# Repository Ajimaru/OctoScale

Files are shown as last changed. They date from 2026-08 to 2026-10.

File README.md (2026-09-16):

<!-- markdownlint-disable MD033 -->
<p align="center">
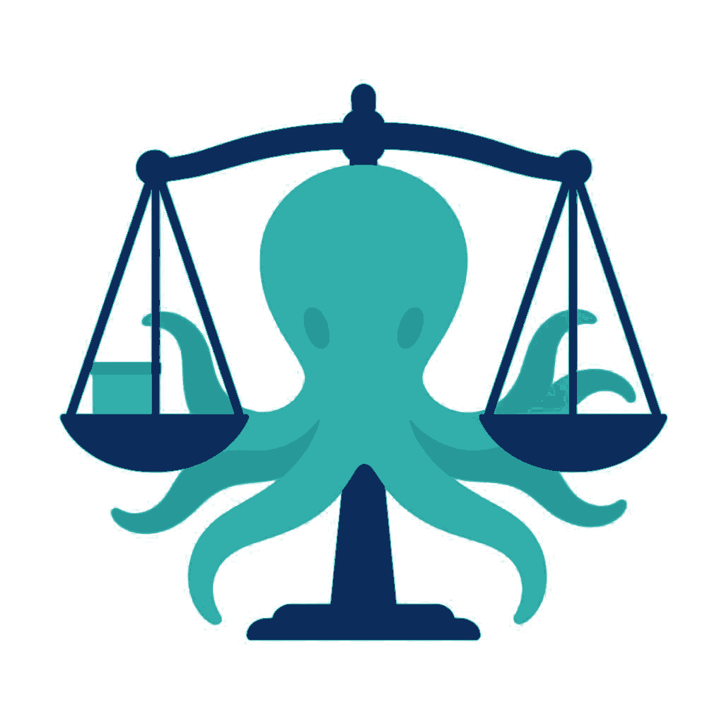
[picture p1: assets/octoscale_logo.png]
OctoScale
  
</p>

<p align="center">
  <b>NFC filament scale for OctoPrint + SpoolManagerExtended.</b><br>
  Weigh a spool, tap its tag, and load it into a printer or save its remaining weight.
</p>
<!-- markdownlint-enable MD033 -->

[](LICENSE)
[](https://github.com/Ajimaru/OctoScale/actions/workflows/build.yml)
[](https://www.espressif.com/en/products/socs/esp32-s3)
[](https://platformio.org)
[](https://github.com/Ajimaru/OctoScale/releases/latest)
[](https://github.com/Ajimaru/OctoScale/releases)
[](https://github.com/Ajimaru/OctoScale)

[badge-license]: https://img.shields.io/github/license/Ajimaru/OctoScale?style=flat-square
[badge-build]: https://img.shields.io/github/actions/workflow/status/Ajimaru/OctoScale/build.yml?style=flat-square
[badge-platform]: https://img.shields.io/badge/ESP32--S3-N16R8-blue.svg?style=flat-square
[badge-pio]: https://img.shields.io/badge/PlatformIO-Arduino-orange.svg?style=flat-square
[badge-release]: https://img.shields.io/github/v/release/Ajimaru/OctoScale?style=flat-square
[badge-downloads]: https://img.shields.io/github/downloads/Ajimaru/OctoScale/total.svg?style=flat-square
[badge-love]: https://img.shields.io/badge/made_with-%E2%9D%A4%EF%B8%8F-ff69b4?style=flat-square

> [!WARNING]
> Database features require [OctoPrint-SpoolManagerExtended](https://github.com/Ajimaru/OctoPrint-SpoolManagerExtended).
> Without it, the device still supports weighing, calibration, and NFC tag operations.

<!-- markdownlint-disable MD033 -->
<p align="center">
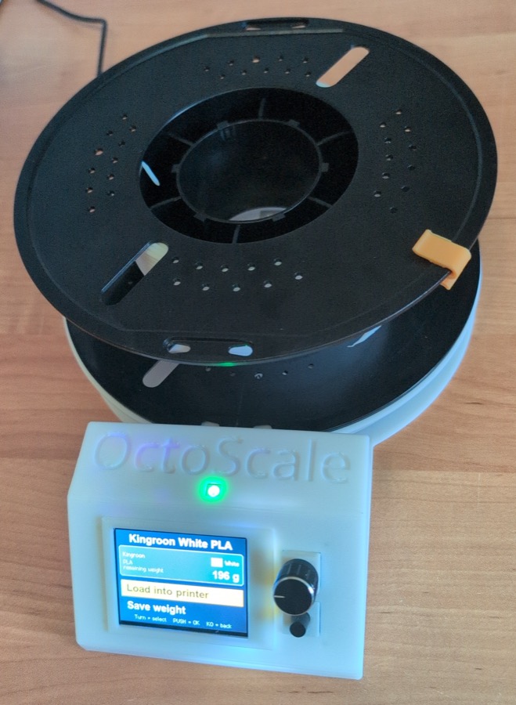
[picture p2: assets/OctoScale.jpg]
Assembled OctoScale with a spool on the scale
  
</p>
<!-- markdownlint-enable MD033 -->

## What it does

OctoScale combines an ESP32-S3, load cell, PN5180 NFC reader, TFT menu, and web UI into one filament-management appliance. It reads spool tags, looks them up in SpoolManagerExtended, loads them into an OctoPrint printer/tool, and writes measured weight back to the database.

It also supports standalone weighing and NFC tag read/write operations, OTA updates, multiple OctoPrint instances, database failover, encrypted configuration backups, and device diagnostics.

## Documentation

The complete build and maintenance documentation is in the Assembly Guide:

- [OctoScale Features](https://github.com/Ajimaru/OctoScale/wiki/Features) — supported scale, NFC, interface, connectivity, OTA, and backup features.
- [Hardware & Printing Guide](https://github.com/Ajimaru/OctoScale/wiki/Hardware-and-Printing-Guide) — hardware BOM and printable enclosure parts.
- [OctoScale Assembly Guide](https://github.com/Ajimaru/OctoScale/wiki/Assembly-Guide) — wiring, enclosure assembly, project layout, and core/task notes.
- [Setup Guide](https://github.com/Ajimaru/OctoScale/wiki/Setup-Guide) — firmware flash, prebuilt `octoscale-usb.bin` and `octoscale-ota.bin` downloads, OTA updates, and first-time setup.
- [Contributing](CONTRIBUTING.md)
- [Security policy](SECURITY.md)
- [Changelog](CHANGELOG.md)
- [License](LICENSE)

The full documentation is maintained in the [GitHub OctoScale Wiki](https://github.com/Ajimaru/OctoScale/wiki).

## License

GNU Lesser General Public License v2.1 or later — see [LICENSE](LICENSE).

Copyright © 2026 Ajimaru

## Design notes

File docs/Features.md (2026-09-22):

# OctoScale Features

NFC filament scale for OctoPrint and SpoolManagerExtended. This page summarizes the device capabilities and supported tag formats. See the [Assembly Guide](Assembly-Guide) for hardware, wiring, enclosure, firmware, setup, and maintenance.

## Scale

- HX711 and 5 kg load cell with live readout on the TFT and web UI.
- One-point quick calibration and two-point linearity-checked calibration.
- Calibration factor stored in NVS and retained across reboots and OTA updates.
- Zero point stored in NVS and checked against a fresh reading at every boot, so a restart while a spool sits on the scale cannot silently adopt that spool's weight as zero. An unconfirmed zero point is shown on the TFT and in the web UI and blocks saving a weight until the scale is tared. Requires a calibrated device.

## NFC

The PN5180 reads and writes NFC-A/NTAG/Ultralight, NFC-V/ISO 15693, and Mifare Classic 1K tags. Supported payload formats are auto-detected:

| Format | Tag | Notes |
| --- | --- | --- |
| `octoscaleExtended` | Mifare Classic 1K | Custom binary layout with CRC-8 commit marker |
| `ntagExtended` | NTAG | Same layout with NTAG page addressing |
| `nfcvExtended` | NFC-V | Same layout with NFC-V blocks |
| `openSpool` / `nfcvOpenSpool` | NTAG / NFC-V | OpenSpool NDEF/JSON, readable by third-party apps |
| `nfcvOpenPrintTag` | NFC-V | OpenPrintTag CBOR, including drying data |
| `tigerTag` | NTAG | TigerTag Standard, unsigned, big-endian 80-byte payload |

Foreign tags such as Snapmaker tags fall back to a UID lookup in SpoolManagerExtended. NFC writes report `droppedFields` when fields do not fit and `unsupportedFields` when the selected format has no representation. Unknown tags can be inspected with a raw sector/block dump.

## Interface and connectivity

- ST7789 320x240 TFT with EC11 encoder menu mirroring the spool workflow.
- Boot splash, locked OTA progress screen, and independent light/dark display theme.
- Three idle stages: dim, bouncing-logo screensaver, and display/backlight off.
- Hidden device test menu: hold PUSH for 3 seconds on the System info screen.
- Web UI themes: OctoScale and OctoPrint, each with light/dark mode.
- Web UI covers weighing, calibration, NFC, OctoPrint instances, system, WiFi, and test points.
- Passive buzzer with event tones and mirrored onboard/external WS2812 status LEDs.
- Optional browser debug console for NFC and HTTP activity.
- WiFiManager provisioning with AP fallback and captive portal.
- OTA through `espota` or web upload/URL update.
- Multiple OctoPrint instances with database failover when instances share an external database.
- AES-256-CBC encrypted JSON backup of the full configuration, including all display, buzzer, and LED settings; API keys are never exported in plaintext.

Continue with the [Hardware & Printing Guide](Hardware-and-Printing-Guide) to gather components and print the enclosure parts.

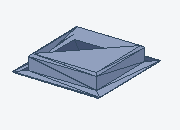
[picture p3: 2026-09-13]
assets/stl-previews/OctoScaleLEDCover.png

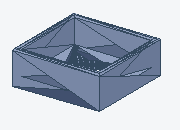
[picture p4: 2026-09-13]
assets/stl-previews/OctoScaleKnobCover.png

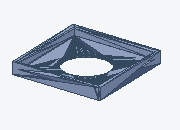
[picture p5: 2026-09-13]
assets/stl-previews/OctoScaleButtonCover.png

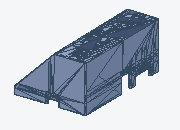
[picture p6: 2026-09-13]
assets/stl-previews/OctoScaleLit.png

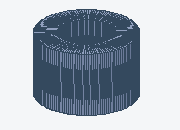
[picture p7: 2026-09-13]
assets/stl-previews/OctoScaleSpacer.png

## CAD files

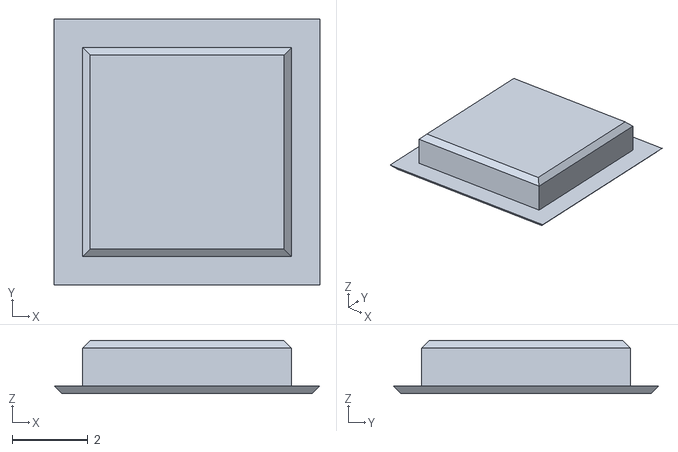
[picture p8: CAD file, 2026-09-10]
stl_files/OctoScaleLEDCover.stl
7.00 x 7.00 x 1.40

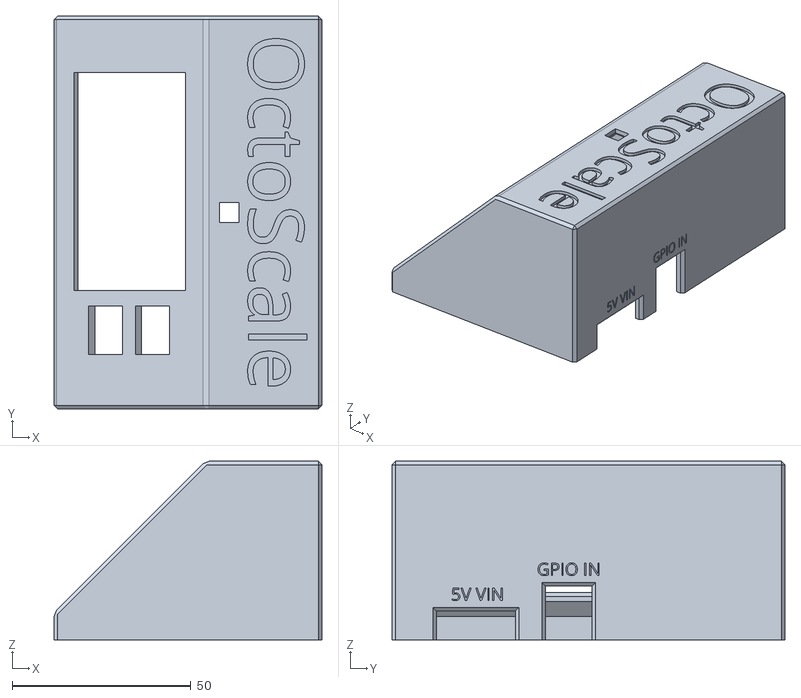
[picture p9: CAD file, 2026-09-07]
stl_files/OctoScaleLit.stl
75.0 x 110.0 x 50.0

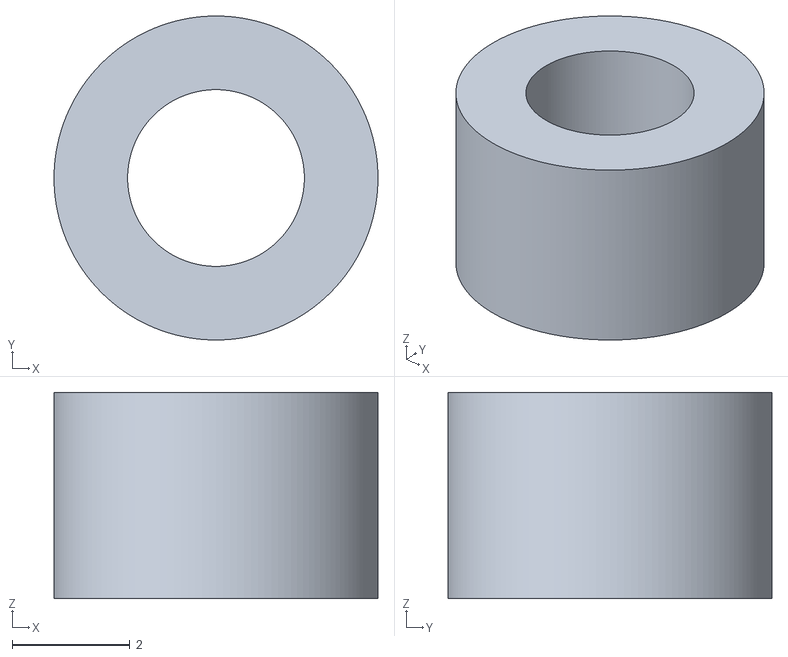
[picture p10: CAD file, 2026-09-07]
stl_files/OctoScaleSpacer.stl
5.50 x 5.50 x 3.50

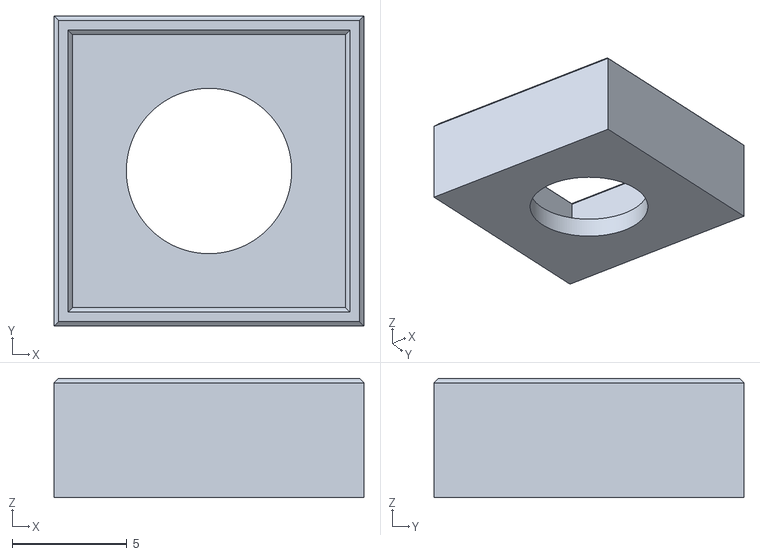
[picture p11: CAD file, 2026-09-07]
stl_files/OctoScaleKnobCover.stl
13.5 x 13.5 x 5.20

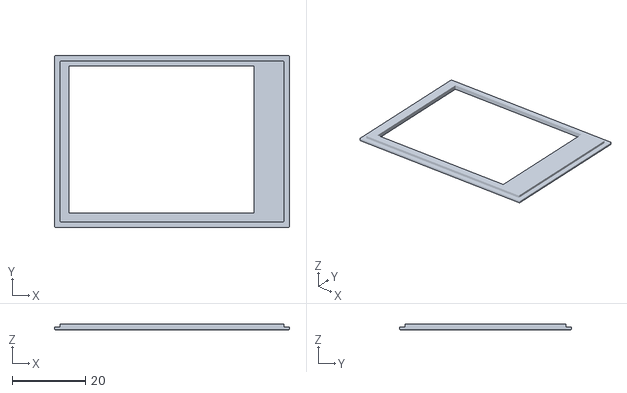
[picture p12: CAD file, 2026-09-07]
stl_files/OctoScaleScreenBazel.stl
64.1 x 47.0 x 1.60

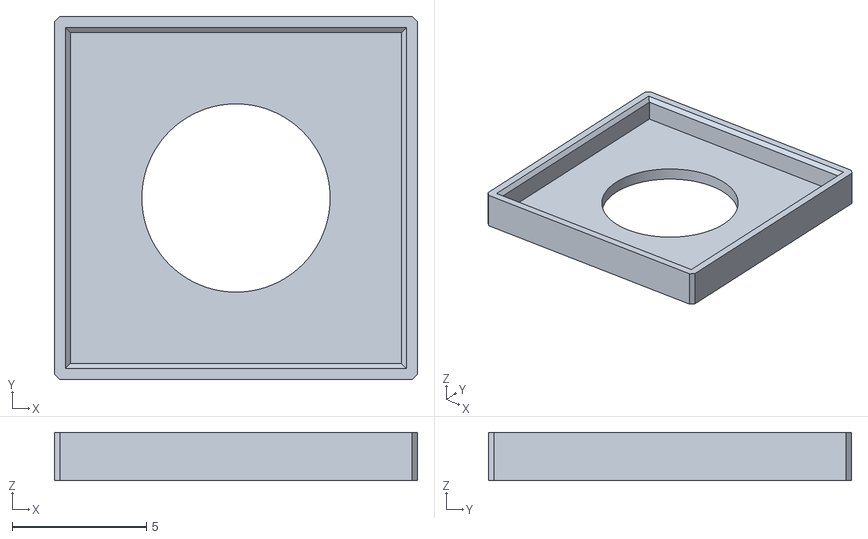
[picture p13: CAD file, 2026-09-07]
stl_files/OctoScaleButtonCover.stl
13.5 x 13.5 x 1.80

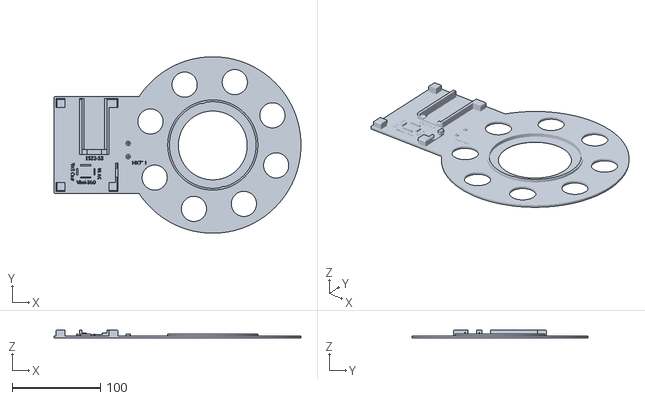
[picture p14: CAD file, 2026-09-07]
stl_files/OctoScaleBottom.stl
280.0 x 200.0 x 9.50

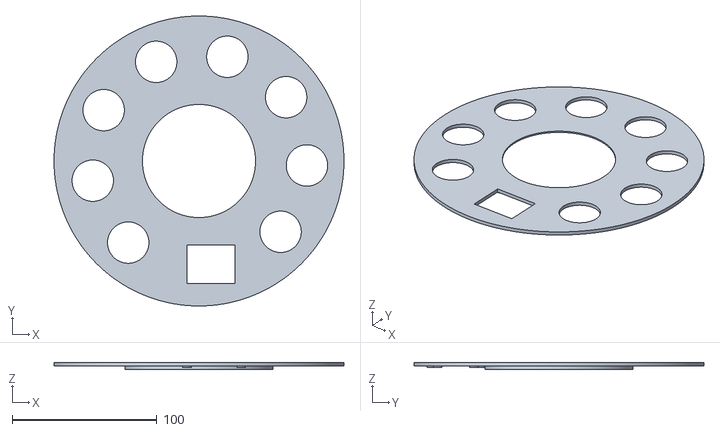
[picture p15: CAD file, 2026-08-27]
stl_files/OctoScale_Top.stl
200.0 x 200.0 x 5.00

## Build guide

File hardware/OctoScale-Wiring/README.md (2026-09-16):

# OctoScale wiring schematic

KiCad 10 project for the wiring diagram in the [Assembly Guide](../../docs/Assembly-Guide.md).
It documents how the modules are wired together; there is no PCB, because the
build is point-to-point wiring between ready-made boards.

## Files

| File | Purpose |
| --- | --- |
| `OctoScale-Wiring.kicad_pro` | project file — open this in KiCad |
| `OctoScale-Wiring.kicad_sch` | the schematic |
| `OctoScale-Modules.kicad_sym` | module symbols (see below) |

## Why a local symbol library

KiCad's stock libraries carry the bare *chips*: `Analog_ADC:HX711` has sixteen
pins named `BASE`, `VFB`, `XI`, `XO` and `RATE`. The board in the BOM is a
breakout with eight labelled holes — `E+ E- A- A+` and `VCC GND DT SCK`. Someone
holding that board cannot match it against the chip symbol without a datasheet.

So every module here is drawn with the pin names printed on its own silkscreen.
Stock symbols are used where they already match what the builder sees:
`Device:Buzzer`, `Device:C_Polarized` and the `power` symbols.

## Checks

The schematic passes ERC with no errors and no warnings:

```bash
kicad-cli sch erc --severity-all --output erc.rpt OctoScale-Wiring.kicad_sch
```

ERC only proves the drawing is self-consistent. That the nets match the firmware
is a separate question, so the netlist is checked against the pin constants in
`src/main.cpp`:

```bash
kicad-cli sch export netlist --output net.net OctoScale-Wiring.kicad_sch
```

All nineteen signal nets, plus the `+5V`, `+3V3` and `GND` rails, were verified
against `src/main.cpp` this way. When a pin assignment changes in the firmware,
update `generate_schematic.py` and re-run that comparison.

## Exports

Images used by the wiki live in `assets/wiring/`:

```bash
kicad-cli sch export pdf --output ../../assets/wiring/OctoScale-Wiring.pdf OctoScale-Wiring.kicad_sch
kicad-cli sch export svg --no-background-color --output ../../assets/wiring OctoScale-Wiring.kicad_sch
```

The PNG in that folder is rendered from the PDF; the wiki embeds the PNG because
GitHub does not render SVG reliably inside `<img>`.

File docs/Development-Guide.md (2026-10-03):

# OctoScale Development Guide

This guide collects public development notes for the ESP32-S3-N16R8 target.

## Target hardware

The supported reference board is an ESP32-S3-N16R8 development board:

- ESP32-S3, dual-core Xtensa LX7
- 16 MB flash
- 8 MB octal PSRAM (OPI)
- WiFi and BLE
- PlatformIO board: `esp32-s3-devkitc-1`
- Environments: `esp32s3` for USB and `esp32s3_ota` for OTA

The firmware does not use PSRAM directly, but the N16R8 memory configuration is required for the reference board to boot correctly. Other ESP32-S3 boards need matching flash and memory settings in `platformio.ini`.

## Build and flash

The first flash is performed over USB with the external power supply disconnected:

```bash
pio run -e esp32s3 -t upload
```

Regular updates use OTA:

```bash
pio run -e esp32s3_ota -t upload --upload-port <device-ip>
```

Use an IP address for OTA. Hostname resolution through mDNS can introduce long delays on some development hosts. Close the serial monitor before flashing; an open monitor can keep the serial port busy and prevent the bootloader handshake.

The reference board uses a WCH USB-UART bridge. The firmware is configured to use UART0 for the serial console rather than native USB-CDC. Keep the USB-CDC boot setting consistent with `platformio.ini` when changing board configurations.

### Dev build numbering

Every local build appends a running number to the version it reports — `0.0.3-dev7` rather than `0.0.3` — and copies its images into `artifacts/`. Flashing the same release version twice is otherwise indistinguishable on the display, in the web UI and over HTTP, which makes "which build is on the device?" unanswerable during a test session.

`tools/dev_build.py` runs as a pre-script for both environments. It increments a counter, passes the result in as `FW_DEV_BUILD`, and after linking writes `artifacts/octoscale-<version>-<env>.bin`, the identical `-ota.bin`, and the matching `.elf`. Keep the `.elf`: a backtrace from the serial monitor cannot be resolved once the build it came from has been overwritten.

The counter lives in `artifacts/.devcounter`, outside version control by way of `artifacts/` already being ignored. A number that changes on every build would otherwise make every test flash look like a source change. `src/version.h` keeps the release number in `FW_VERSION_RELEASE` and falls back to it when `FW_DEV_BUILD` is absent, so a clean checkout reports a plain version with no dev suffix. Rename one of those macros and the script's pattern has to follow, or the version silently reads as `0.0.0`.

`tools/dev_build.py` runs as a pre-script for *every* build via the shared `s3_base` environment, including CI — a release build is not naturally exempt. The release workflow (`.github/workflows/release.yml`) sets `OCTOSCALE_RELEASE_BUILD=1` before invoking `pio run`; the script checks that flag and, when set, skips both the dev suffix and the `artifacts/` archiving, so the published firmware reports the plain `FW_VERSION_RELEASE` instead of `<version>-dev<N>`.

Check what actually shipped by reading the binary rather than the build log, which only shows what the script intended:

```bash
strings artifacts/octoscale-0.0.3-dev1-esp32s3.bin | grep -o "0\.0\.3-dev[0-9]*"
```

The dev number separates local builds from each other; it does not make released versions unambiguous. Twenty-one commits shipped between the 0.0.2 and 0.0.3 bumps, all reporting the same version. Treat `fwVersion` and `currentVersion` as diagnostics rather than as a behaviour switch, and do not branch on them: a version that stays constant across that many commits separates nothing, and a later bump marks only devices built after it, never the ones already in the field. Where a consumer needs to know whether a capability exists, test for the field itself — `idSource` is simply absent on firmware that predates it.

## Boot and memory configuration

The ESP32-S3-N16R8 configuration requires:

- `board_build.arduino.memory_type = qio_opi`
- `-DBOARD_HAS_PSRAM`
- USB-CDC-on-boot disabled for the UART0 console configuration

Without the OPI memory setting, an N16R8 board may compile successfully but fail during boot. For boards without octal PSRAM, remove the PSRAM build flag and use the board's correct memory type. Boards with less than 8 MB flash need a custom partition layout and are not supported by the default OTA setup.

## Core split and ownership

The firmware deliberately separates blocking hardware work from networking:

- Core 0 runs `scaleTask` for the HX711 and `pn5180Task` for NFC polling, TFT menu work, and encoder input.
- Core 1 runs `loop()` with WiFi, HTTP, OTA, database checks, and flow delegation.
- Blocking NFC operations stay on core 0 because the PN5180 library contains unbounded wait loops.
- Flow actions that require blocking HTTP calls are passed to `loop()` through volatile state/flags.

A new hardware operation must not block the web server. Keep ownership of each peripheral within its task and communicate across cores with the existing state and flag pattern.

`pn5180Task` iterates at roughly 100 Hz for encoder debounce and menu work. Only the tag poll is throttled, by `PN5180_POLL_INTERVAL_MS` in `src/main.cpp`. Write, erase, and read requests are picked up on every iteration, so they are unaffected by that interval. Express any duration in this task in real milliseconds rather than as a count of poll ticks: a tick count silently changes meaning whenever the interval moves, which is how error screens once stayed up for a different length of time than intended.

## Pin map

The reference pin assignment is collision-checked against ESP32-S3 strapping pins, USB pins, and OPI flash/PSRAM pins.

| Peripheral | Signal | GPIO / supply |
| --- | --- | --- |
| HX711 | `DOUT`, `SCK` | 5, 6; 3.3 V |
| PN5180 FSPI | `MOSI`, `SCK`, `MISO` | 11, 12, 13 |
| PN5180 | `NSS`, `BUSY`, `RST`, `IRQ` | 10, 14, 21, 47 |
| TFT HSPI | `SCL`, `SDA` | 42, 44 |
| TFT | `CS`, `DC`, `RES`, `BLK` | 38, 39, 40, 41 |
| Encoder | `A`, `B`, `PUSH` | 15, 16, 17 |
| Start button | `KO` | 18 |
| Passive buzzer | signal | 7 |
| Onboard WS2812 | data | 48 |
| External WS2812 | data | 9 |

Do not reuse GPIO 0, 3, 45, or 46 (strapping), GPIO 19 or 20 (USB), or GPIO 26-37 (OPI flash/PSRAM on the reference board). GPIO 44 is often labelled `RX` on the development board. GPIO 43 is the UART0 transmit pin and should remain reserved when serial monitoring is needed.

## SPI buses

The PN5180 and TFT must use separate SPI controllers:

- PN5180: FSPI, GPIO 11/12/13
- TFT: HSPI, GPIO 42/44

Sharing the buses can leave the PN5180 unable to read tags after TFT initialization. The TFT is write-only and therefore does not need MISO. Keep `USE_HSPI_PORT` enabled for the TFT_eSPI configuration.

## Power requirements

The external 5 V supply powers the PN5180 RF section and TFT. A regulated 3.3 V rail powers the HX711, PN5180 logic, and external WS2812. All modules must share ground.

The PN5180 needs a 470 uF capacitor directly across its 5 V and ground pins. RF current spikes can otherwise collapse the supply and appear as a software or SPI failure. Do not power the ESP32-S3 from USB while an external 5 V supply is connected to its 5 V/VBUS/VIN input.

Two more electrolytic capacitors buffer the rest of the build:

| Position | Part | Buffers |
| --- | --- | --- |
| ESP32-S3 `5V` to `GND` | 1500 uF, 10 V+ | the board's own supply through WiFi transmit bursts |
| Mini-360 `OUT+` to `GND` | 100 uF, 16 V+ | the 3.3 V rail feeding HX711 and PN5180 logic |

Mount both with short leads directly at the pins they buffer; a few centimetres of wire undoes most of the benefit. Observe polarity.

The 3.3 V capacitor belongs at the **converter output**, not at the ESP32-S3's `3V3` pin. That pin is an output of the board's own regulator and feeds nothing in this build — HX711 and PN5180 logic hang on the Mini-360. A large capacitance on a regulator's output also does it no favours.

If the device resets unpredictably, read `resetReason` from `/system` first: value 9 is a brownout and points at the supply path rather than at firmware. Prefer a short, thick, direct connection, and put any remote power switching on the mains side of the 5 V supply rather than in the low-voltage path.

## Input handling

The EC11 encoder uses quadrature interrupts on both rotation pins. PUSH and KO use interrupt-latched button events with debounce. This prevents a button press from being lost while the reader is inside a blocking NFC operation. Preserve this event-latching behavior when adding controls.

The encoder and buttons use internal pull-ups; the other side of each switch connects to ground. If rotation direction is reversed, swap the A and B signals.

## NFC development

`src/pn5180nfc.h` supports NFC-A/NTAG/Ultralight, NFC-V/ISO 15693, and Mifare Classic 1K. The PN5180 library is vendored under `lib/PN5180 Library/` and contains project patches; consult `lib/README-patch.md` before changing it.

The reader supports database-ID writes as well as extended spool payloads. Extended payload formats are selected by tag family and can include material, vendor, color, diameter, weights, and temperatures. NFC-V and NTAG formats may use either the project layout or OpenSpool-compatible NDEF where supported.

Keep NFC work asynchronous at the HTTP boundary: start operations with the existing start endpoints, poll their status endpoints, and avoid long reader calls in request handlers. The three single-shot status endpoints — `/nfcwritestatus`, `/nfcdumpstatus` and `/nfcreadstatus` — each hand out their result exactly once and clear it, so a second reader cannot tell "someone already collected it" from "nothing happened". Pass `?peek=1` to read without consuming (and, on the write status, without the LED flash that announces the outcome) when something other than the issuing client wants to follow along. Keep the three consistent: `peek` was first added to the write status alone, and the gap on the dump endpoint was found by an external consumer rather than here. A fourth status of this shape needs the same flag. Unknown tags can be inspected through the raw dump/image paths without changing the normal spool flow.

### Vendored PN5180 patches

The local PN5180 library contains four project changes documented in `lib/README-patch.md`:

1. BUSY-pin waits have a timeout instead of an unbounded loop. A non-conforming tag must produce a clean failure rather than hanging the reader task indefinitely.
2. `mifareAuthenticate()` implements the PN5180 `MIFARE_AUTHENTICATE` host command, which is required for Mifare Classic sector access.
3. The IRQ wait loops in `setRF_on()`, `setRF_off()`, and `reset()` have timeouts. Upstream spins on these without any bound, so an unresponsive chip starves the reader task on core 0 and trips the task watchdog — a reboot with no log at all when the device runs from external power with no serial host attached.
4. ISO 15693 command handling waits for the reception interrupt instead of a fixed `delay(10)`. The old fixed delay discarded answers from slower tags as "no card". The wait is split in two: first for the start of a frame, bounded tightly because that timeout is paid on every empty poll, then for reception to complete. Do not collapse these back into a single check — a write is only acknowledged after the tag's internal programming cycle, so the frame legitimately has not started yet when the command returns.

Recheck all four when updating the vendored library. NFC-A probing also requires CRC to be disabled for REQA/ATQA and anticollision frames. Seven-byte UIDs need the cascade-level anticollision sequence. Mifare Classic writes use a two-step command/data exchange, while NTAG page writes require a fresh RF reset and re-selection for each page. After NFC-A work, restore the reader with `reset()` and `setupRF()` before returning to normal NFC-V polling.

The legacy database ID is an ASCII decimal value stored in the tag's legacy area. Extended payload reads happen before flow lookup and take priority over the legacy ID. This ordering matters because an OpenSpool NTAG payload can overwrite the legacy pages and stores its ID as `os_db_id` in the NDEF/JSON data instead.

### Trusting a parsed database ID

The legacy layout is digits followed by space padding, with no magic number and no checksum. Nothing in it identifies the tag as ours. A third-party tag that happens to carry ASCII digits at the same offset — an inventory number, for instance — parses exactly like a tag this firmware wrote, and no amount of reading that field harder can tell the two apart.

The parser therefore only rejects shapes our own writers cannot produce: trailing content that is not padding, more than one run of digits, a leading zero, or more than ten digits. Everything surviving that is plausible, not proven.

It also requires the digit run to end inside the buffer it was given, with at least one padding byte visible. `pn5180ReadNfcvId` passes however many bytes it managed to read, so a block failing mid-field used to yield a prefix of the real ID — a five-digit ID read as four bytes returned a different, entirely plausible, wrong spool, with no error anywhere. The ten-digit ceiling is mirrored in the three ID writers; a wider value would be written and verified, then read back as `-1` for the rest of the tag's life.

Proof, where it exists, comes from a second source. `occupancy` reads the Capability Container and the start of the data area, so it knows whether the tag carries a format this firmware wrote; the ID parser reads a fixed offset and knows nothing about the CC. `/nfcprobe` reports the combined judgement as `idSource`:

| `idSource` | Meaning |
| --- | --- |
| `extended` | The ID arrived with a verified format magic (`OX`, `OS`, OpenSpool NDEF, TigerTag). As trustworthy as the format it came from. |
| `legacy` | The ID came from the header-less field and passed the shape check. Plausible, unverifiable. |
| `unverified` | A `legacy` ID on a tag whose `occupancy` is `foreign`. The data area belongs to a format this firmware did not write, so the digits are most likely someone else's numbering. |
| `extendedNoId` | A verified format that carries no database ID of ours at all — TigerTag and OpenPrintTag both describe a spool without referencing this database. |
| `""` | No ID was parsed. |

`extendedNoId` is deliberately not `""`. Both mean "no usable ID", but the tag is not blank: it holds structured data from a format this firmware can read. A consumer that collapses the two will offer to overwrite a TigerTag.

A tag that has just been placed on the reader is published in two steps: type and UID appear as soon as it answers, because the display needs them at once, while the ID and the format fields are only filled after the Extended read and the occupancy probes have run — a few hundred milliseconds on NTAG. `/nfcprobe` reports `complete: false` for that window. A consumer that polls continuously can ignore the flag and watch the fields settle; one that asks once and acts on the answer should require `present && complete`, or it may see an Extended tag as an empty one and offer to overwrite it. Firmware older than this field omits it, so treat a missing value as unknown rather than as false.

`idSource` is a reported judgement, not an input to the flow. The load flow reaches its own verdict from the raw values — `hasExtendedData` and `occupancy` — and `flowWouldUse` only consults `idSource` to exclude `unverified`. Keep it that way: the firmware decides on what it read, the consumer receives the summary. It also means the current formats' habit of leaving `idParsed` at `-1` whenever `extendedNoId` applies is a property of those formats, not a guarantee of the field. A future format with both a verified magic and a populated legacy area would break that assumption, so do not build logic on it without checking the callers again.

`idParsed` keeps the raw value even when `idSource` is `unverified`, because `/nfcprobe` is a diagnostic endpoint and "there are digits here, but they are not credible" is worth more to a caller than a bare `-1` that cannot be told apart from an empty field. The judgement, not the value, is what consumers should branch on. `flowWouldUse` and the load flow both refuse an `unverified` ID and fall back to the UID lookup.

Note that `occupancy` alone is not that judgement. A tag written through `/nfcwriteid` onto previously NDEF-formatted material reports `foreign` while carrying a perfectly real ID, and an extended tag can report `foreign` because `occupancy` only inspects the CC and the first user page. Branching on `occupancy` instead of `idSource` discards both. Firmware older than this field omits it entirely, so a consumer that needs to support both should treat a missing `idSource` as "unknown, ask the user" rather than inferring one from `occupancy`.

`writeFormat` and `formatLabel` answer a different question again: which format this firmware *would* write if asked right now. They are derived from the tag family alone and say nothing about what is currently on the tag — every non-Classic NFC-A tag reports `openSpool` whether or not it holds any NDEF at all. Use `hasExtendedData`, `occupancy`, and `idSource` to find out what a tag actually carries.

## Display, LED, and buzzer

The TFT uses TFT_eSPI configured through `platformio.ini` build flags. The backlight is controlled by LEDC PWM on GPIO 41; do not hand the backlight pin to TFT_eSPI in a way that lets display initialization override the PWM. At runtime only `pn5180Task` writes the backlight: `/backlight` and `/display` set the level and count as activity, and the task applies it on its next loop pass. Level 0 detaches LEDC and holds the pin LOW as a plain GPIO. Coming back, the pin is re-attached before the level is written: `ledcAttachPin()` re-applies the duty it reads back, and the read-back shows a new duty only from the next PWM cycle on.

The display is off in the third idle stage and whenever the target brightness is 0. Off means backlight off on an all-black frame with the controller awake; `DISPOFF`+`SLPIN` would save about 15 mA, but on the reference panel backlight flashes were visibly stronger in sleep mode (cause not established). Nothing is drawn while off, and the input that wakes the display is consumed.

The onboard WS2812 on GPIO 48 and the external enclosure LED on GPIO 9 are mirrors. Drive both through the shared LED helper so color and timing stay synchronized. The passive buzzer uses LEDC PWM and shares event state with the LED pulse logic.

The LED base states are boot/WiFi connection, AP provisioning, connected/idle, database check, NFC result, and OTA progress. OTA has priority over normal animation; buzzer-linked colors have priority over the idle breathing effect. Keep all normal pixel writes behind the shared LED helper so the two pixels cannot drift apart or compete for the RMT peripheral. The idle breathing effect is deliberately low brightness. If colors are wrong, check whether the module is wired RGB rather than GRB before changing firmware behavior.

The TFT has four important takeover screens: the boot splash, the idle logo screensaver, the OTA lock screen, and the NFC-write screen. OTA suppresses backlight dimming and consumes input until the update finishes. NFC writes are blocking inside the reader task, so the write screen is intentionally static; a timer animation would not advance while the task is inside the write call. A completed write screen remains until the HTTP status result is consumed.

## Debug console and memory

The optional web debug console is an in-RAM ring buffer intended to replace serial monitoring when the device runs from external power. Logging is inert while disabled. Keep the buffer bounded and avoid serializing it when free heap is low: `/debuglog` should fail clearly rather than allocating a second large contiguous JSON string and taking down the web server. High-frequency traces, such as repeated successful Mifare authentication or unchanged weight readings, must be gated or rate-limited. Prefer chunked streaming if substantially more history is ever needed.

Display wakes are logged once per quiet period as `Display: activity (<source>) after <n>s idle`, which names an unexpected waker directly. The console's *Backlight trace* switch (`/debuglog?bldiag=1`, reported as `blDiag`, not persisted) adds a `BL diag` line every 10 s: idle time, target, current and read-back level (`hw`), and whether the display is off.

`/diag` switches off suspected sources of display interference one at a time, without a reflash. Nothing it sets is persisted; without parameters it returns the current state as JSON. The response also carries `asleep` (display off), `blPwm` (LEDC attached to the pin) and `blHw` (duty read back from the LEDC channel, 256 = fully on).

| Parameter | Effect |
| --- | --- |
| `nfc=0` / `nfc=1` | Pause the tag poll with the PN5180 RF field off / resume. No tags are detected while paused. |
| `led=0` / `led=1` | Stop LED updates with both pixels dark / resume |
| `tx=34`…`84` | WiFi TX power in 0.25 dBm steps (80 = 20 dBm, the default) |
| `panelsleep=1` / `0` | Display off uses `DISPOFF`+`SLPIN` / the awake black frame; applies at the next off |

## WebUI polling and tab ownership

The WebUI is embedded in `src/web_ui.h`. Periodic status requests are owned by the tab that displays their data. The `currentTab` guard prevents hidden panels from polling, and the browser visibility guard stops all periodic requests while the page is hidden. Selecting a tab triggers one immediate refresh; the regular timer then continues only while that tab remains active.

| Tab | Endpoint | Interval |
| --- | --- | ---: |
| Operate | `/weight` | 500 ms |
| Operate | `/flow/status` | 800 ms |
| NFC | `/nfc5180` and `/flow/status` | 700 ms |
| Scale | `/scaleinfo` | 1000 ms |
| Setup | `/wifi/status` | 5000 ms |
| System | `/system` | 3000 ms |
| Debug | `/nfcdebug` | 700 ms |
| Debug diagnostics | `/nfc5180`, `/scaleinfo`, `/weight` | 1000 ms |

`/weight` answers `<grams>|<zeroState>|<deviation g>` as plain text rather than a bare number. The zero-point verdict rides along on that poll instead of being fetched separately so the Operate tab's reading and its warning can never disagree on screen; a consumer that only wants the weight takes the first field.

The Debug tab has two additional conditional loops. The menu preview polls `/menupreview` every 300 ms only while the preview is active. The debug console polls `/debuglog` every 500 ms only while debug logging is enabled. These loops stop when the Debug tab is left or the browser page is hidden.

The header status LEDs are the one deliberate exception to tab ownership: they poll `/system` and `/wifi/status` every 10 s regardless of the active tab, because they are visible from all of them. They are still gated on page visibility, and the visibility handler refreshes them on return so they do not show stale state.

Any self-rescheduling loop needs both guards, not just the visibility one. The preview auto-cycle in particular kept stepping the device's screens from a switched-away tab, and an active preview suppresses NFC polling on the device — so a forgotten auto-cycle silently stopped tag detection while the page looked idle. When adding a loop that reschedules itself with `setTimeout`, check `document.hidden` and `currentTab` on every iteration, and make sure the tab's `tabRefresh()` path restarts it.

The intervals are intentionally different: live weight and flow state need responsive updates on Operate, while WiFi and system metrics can use a lower rate. Avoid adding a global timer for a panel-specific endpoint. Add the endpoint to the owning tab's `tabRefresh()` path and wrap its periodic callback with `pv(callback, tabId)` so it cannot continue polling in the background.

The page also performs one-shot requests during startup and user actions, such as loading `/factor`, `/display`, `/led`, `/buzzer`, `/db/get`, and OctoPrint configuration. These are not periodic status polls and should remain tied to the relevant initialization or action unless a new live status requirement is introduced.

## Spool flow architecture

The UI-independent flow is:

`idle -> db_check -> ask_action -> ask_printer -> ask_tool -> loading` or `weigh_confirm -> weighing -> done/error`

The reader task detects the tag and raises a flow request. The networking loop performs the blocking SpoolManager call. Database lookup uses the database ID when one is available and credible, and falls back to the tag UID for foreign tags. An ID parsed out of the header-less legacy area of a tag whose `occupancy` is `foreign` is deliberately not used (see "Trusting a parsed database ID"); the flow treats such a tag as having no ID at all and says so on the display, rather than silently loading whichever spool happens to share that number. Loading fetches the printer's tool count before selecting a tool. Weighing uses the live gross reading and only offers a remaining-weight calculation when empty and total spool weights are known.

Tag removal keeps action/printer/tool selection open for the configured timeout. The weighing states are exempt because the spool can hide its tag while it remains on the scale. Keep this state-machine behavior independent of whether the request came from the TFT or web UI.

## Persistent configuration and backup

Preferences are stored under the `octoscale` namespace. Important keys include the calibration factor, the tare offset and the factor it was written under, OctoPrint instance JSON, selected database instance, selection timeout, display brightness/timeouts, screensaver settings, buzzer settings, and debug-console enablement. WiFiManager stores WiFi credentials separately.

Configuration backup is JSON. API keys are encrypted only when a passphrase is supplied, using PBKDF2-HMAC-SHA256 and AES-256-CBC with a random salt and IV. Without a passphrase, keys are omitted rather than exported in plaintext. Restore validates and decrypts the complete file before writing anything to NVS, so a bad password must leave the running configuration unchanged. The backup protects the file, not an unencrypted LAN transport.

Device settings travel in a `settings` object addressed by NVS key, driven by the `BK_SETTINGS` table in `backup.h`. Adding a setting means adding one row there; export and import both walk the same table, so they cannot drift apart. Each row records the width the value is written with, because Preferences returns 0 when a `uint8` key is read back as `uint16`. Export skips keys that were never written, and import skips keys the file does not contain — an old backup therefore leaves newer settings at the running firmware's defaults instead of resetting them, which is also why the format version stays at 1. The table goes through NVS rather than the matching globals because `g_menuDark` is file-static in `menu.h`, included long after `backup.h`.

`bkImport` only writes NVS. The `/restore` handler re-reads those keys into the globals afterwards and re-applies the theme and LED routing, since the running firmware holds them in RAM; without that, a restore appears to have been ignored until the next boot.

## Zero point and tare

The tare offset is persisted (`tareOff`), together with the calibration factor that was in effect when it was written (`tareOffFac`). Both are needed: an offset in ADC counts cannot be read as grams without its factor, so after a recalibration a gram threshold computed from the new factor against an offset written under the old one would be wrong. `applyCalFactor` therefore carries `tareOffFac` forward — without that line the stored offset would count as stale after every calibration.

`startScale` no longer tares unconditionally. It calls `scaleZeroEvaluate`, which reads a short quiet window and compares its mean against the stored offset. Within tolerance the offset is refreshed from the fresh reading, which keeps temperature drift from accumulating. Outside tolerance the stored offset wins and nothing is written — the scale then displays the load that is actually on it instead of zero.

The four states are reported as `zeroState` in `/scaleinfo`, with `zeroTrusted` as the field to branch on. `suspect` deliberately claims only that the reading deviates, never why: a single measurement cannot separate a load on the platform from cell drift or a rebuilt mechanism, so the firmware reports the observation and leaves the cause open. `unstable` means the boot window was too noisy to support any statement at all.

`scaleTask` also flips a trusted zero to `suspect` when the reading drops well below zero at runtime. That is the one case no boot check can see: boot with a load, load removed afterwards. The negative reading is still clamped for display, but the state is set before the clamp — the clamp used to destroy exactly this information.

Weighing is refused while the zero point is not trusted, at both entry points and again inside `flowDoWeighSave`, because that path writes to the database and then onto the tag, and neither has a way back. A manual tare is the only way out of `suspect` and `unstable`; it deliberately performs no empty check, since a permanently mounted holder legitimately belongs to the zero point and the firmware cannot tell it apart from a spool left on by accident.

Both surfaces report the same thing the same way: the reading takes the warning color and a line underneath names the deviation and the remedy, on the TFT idle screen and in the Operate tab's weight card. The warning color is per theme in both (`MENU_WARN_FG` on the display, `--warn-fg` in CSS) because one amber cannot serve both backgrounds — the tone that stands out on black washes out on white. It is deliberately not the error red, which means "broken" on the footer chips, whereas an unconfirmed zero point is not a fault.

Thresholds live in grams (`SCALE_ZERO_TOL_G`) and convert to counts at runtime, with a floor so they never fall under the cell's own noise. On an uncalibrated device the factor is the 1.0 placeholder, grams are meaningless, and the stored offset is treated as not comparable — the guard is inactive until the device is calibrated.

## WiFi and OctoPrint integration

WiFiManager provides normal station setup, AP fallback, captive portal, credential storage, reconnect attempts, and WiFi scanning. Keep connection retries and timeouts long enough for slow routers before starting the fallback AP.

OctoPrint communication goes through the SpoolManagerExtended HTTP bridge. API keys stay in NVS and are never written to development documentation. The device supports multiple OctoPrint instances and can fail over between instances that report the same external database identity. It does not connect directly to MySQL.

## Debugging checklist

1. Confirm the selected PlatformIO environment matches the board memory configuration.
2. Disconnect external power before USB flashing.
3. Close serial monitors before uploading.
4. Verify the PN5180 has external 5 V, common ground, and the local 470 uF capacitor, and that the board's 5 V pin and the converter output are buffered.
5. For unexplained resets, read `resetReason` from `/system` before suspecting firmware: 9 is a brownout and points at the supply path, 6 is a task watchdog, 1 is a normal power-on.
6. Confirm PN5180 and TFT are on separate SPI buses.
7. Check the serial console for boot progress and WiFi/AP status.
8. Use the web UI diagnostics for HX711 readiness, raw value, noise, system metrics, and debug logging.
9. Test with the device IP before investigating hostname or mDNS delays.

## Code structure

| Path | Development responsibility |
| --- | --- |
| `src/main.cpp` | Tasks, WiFi/OTA, HTTP endpoints, flow state, peripheral setup |
| `src/pn5180nfc.h` | NFC detection, read/write operations, payload formats |
| `src/display.h` and `src/menu.h` | TFT initialization, menu, screensaver, OTA screen |
| `src/encoder.h` | Encoder ISR and debounced button events |
| `src/web_ui.h` | Embedded HTML, CSS, and JavaScript served from PROGMEM |
| `src/octoprint.h` and `src/spooldb.h` | OctoPrint instances, bridge calls, database failover |
| `src/backup.h` | Encrypted configuration backup and restore |
| `src/dbglog.h` | Optional in-RAM debug ring buffer |
| `platformio.ini` | Board, memory, pin, library, and build configuration |
| `lib/PN5180 Library/` | Vendored and patched PN5180 driver |

When changing public behavior, update the relevant guide under `docs/` and keep endpoint names, task ownership, and NVS behavior documented. Do not add local machine paths, API keys, WiFi credentials, MAC addresses, or private test data to committed documentation.

## Documentation and wiki sync

`docs/` is the single source of truth. Every file there is a wiki page and the filename is the page name. The `wiki-sync` workflow copies `docs/*.md` to the GitHub wiki on every push to `main` that touches them, and can also be run manually from the Actions tab. **Edits made directly in the wiki are overwritten by the next sync** — change the file under `docs/` instead, or the change is lost the next time anyone edits documentation.

The wiki's `Home` page is not synced and has no counterpart in `docs/`. It is a short landing page with its own navigation and images, maintained in the wiki itself.

Anything that a consumer of the HTTP API can rely on belongs in this guide rather than only in a code comment. A promise that lives in the implementation holds only until someone rewrites the implementation; a documented one makes a later change the maintainer's problem instead of a downstream surprise. Any field the firmware accepts is part of the contract whether or not it is written down — the only choice is whether that contract is legible.

The documentation workflow ends here. Return to the [Features](Features) page for the project overview.

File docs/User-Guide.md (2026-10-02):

<!-- markdownlint-disable MD033 -->

# OctoScale User Guide

This guide covers day-to-day operation: the first run after assembly, the TFT menu, the web UI, and what to do when something looks wrong.

If the device is not built and flashed yet, start with the [Assembly Guide](Assembly-Guide) and the [Setup Guide](Setup-Guide). The [Setup Guide](Setup-Guide) owns build, flash, and first-time configuration; this page picks up once the device is on the network and calibrated.

## Initial setup

The [Setup Guide](Setup-Guide) covers flashing and the configuration steps in the web UI. Once that is done, the first thing worth doing is a full pass on the device itself, because it confirms the hardware independently of the network.

### Confirm the hardware before trusting a reading

A freshly assembled unit can pass a web UI check and still have a cold solder joint on the encoder or a buzzer wired backwards. The device has a hidden test menu for exactly this.

**To open it:** from the idle screen press PUSH to reach the Device menu, turn to **System info**, press PUSH to open it, then **hold PUSH for about 3 seconds**. A confirmation beep means the test menu is open.

The gesture is deliberately awkward. System info is already two deliberate steps from idle, so a held PUSH there will not fire by accident, and holding a single button is reliable in a way that a two-button combination is not on this hardware.



</br>

|  |  |
| --- | --- |
| **NFC test** — reader initialises, tag detected, UID read. Reader must show `ready`; a tag on the platform shows `present` plus its UID. | **Scale test** — load cell and HX711 respond. Press the platform: the number must move and return. |

|  |  |
| --- | --- |
| **LED test** — turn to step Red/Green/Blue/White/Off. **Both** WS2812 must show the same colour; if they differ, they are not sharing the LED helper. | **Buzzer test** — PUSH plays the test tone. Silence here with the buzzer enabled means a wiring fault. |

|  |  |
| --- | --- |
| **Screen test** — three pages: full-screen colours, font sample, grayscale ramp. Catches dead pixels and colour-order faults. | **Button test** — guided: press PUSH, then KO. Confirms both buttons are wired and debounced. |

|  | |
| --- | --- |
| **Knob test** — guided: turn CW, then CCW. If the directions are reversed, swap `A` and `B` on the encoder. | |

Inside a sub-test, hold PUSH again to return to the test list; from the list, hold PUSH to leave. Button and Knob tests need this because they consume normal presses as test input and so have no short-press way back.

### First spool

1. Put a tagged spool on the platform.
2. If the tag is blank, write it from the web UI: **NFC → Write ID to tag**.
3. The device reads the tag, looks the spool up, and offers **Load into printer** or **Save weight**.

If the lookup fails, see [Troubleshooting](#troubleshooting) below — the message on screen distinguishes the cases.

## TFT user guide

### Controls

The whole interface is three inputs.

| Input | Action |
| --- | --- |
| Turn knob | Move the selection |
| PUSH (knob press) | Confirm / open |
| KO (second button) | Back / cancel |

Every screen that takes input shows its own hint line at the bottom, so the current meaning of each control is always on screen.

### Idle screen

The resting state shows the live weight in large digits, with a status footer for **NFC**, **Scale**, **DB**, and **WiFi**. A tag on the reader adds its carrier type (`NFC-A`, `NFC-V`, …) under the weight.

| No tag | Tag present | Not yet calibrated |
| --- | --- | --- |
|  |  |  |

If the scale has never been calibrated, the idle screen carries a `Calibrate scale in web UI` warning. The weight shown before calibration is not meaningful.

After a period with no input the display steps down through three stages, all configurable in the web UI under System → Display:

1. **Dim** — backlight drops to the dim level (default after `timeout` seconds). A dim level of 0 turns the display off instead.
2. **Screensaver** — a bouncing logo, default after 60 s.
3. **Off** — display and backlight off, default after 300 s, if enabled.

All three timeouts are in seconds. While the display is off, the first turn or press only wakes it and triggers nothing else.

| Boot splash | Screensaver |
| --- | --- |
|  |  |

Any input or any state change (a tag arriving, for instance) returns to the normal display.

### Loading a spool

Placing a tagged spool on the platform starts the flow automatically.

1. **Checking DB…** — the spool is looked up by tag ID, or by UID for a foreign tag.
2. **Spool found** — vendor, material, colour swatch and remaining weight, then a choice:
   - **Load into printer** → choose printer → choose tool → **Loaded**
   - **Save weight** → **Saved**
3. Both paths end on a result screen that returns to idle.

| 1. Lookup | 2. Spool found | 3a. Choose printer |
| --- | --- | --- |
|  |  |  |

| 3b. Choose tool | 4a. Loaded | 4b. Saved |
| --- | --- | --- |
|  |  |  |

The **Save weight** path is also the unload path. It shows `Put on scale` with a live reading and the expected remaining weight, so you can confirm the spool is seated before PUSH commits the value.



### Device menu

PUSH or KO from idle opens the Device menu.

| Item | Effect |
| --- | --- |
| **Tare** | Zeroes the scale; confirms with `Tared` and returns automatically |
| **NFC debug: ON/OFF** | Replaces the idle screen with a live tag readout — carrier, UID, usable bytes, and whether a spool ID resolved |
| **Buzzer: ON/OFF** | Master buzzer switch |
| **Theme: Dark/Light** | Display theme, independent of the web UI theme |
| **System info** | WiFi signal, IP, NFC/Scale/DB status, printer count, firmware version |

| Device menu | System info |
| --- | --- |
|  |  |

**NFC debug** is the fastest way to tell an unreadable tag from an unassigned one: it shows the carrier and UID even when no spool ID could be resolved.

| No tag | Spool found | No spool ID |
| --- | --- | --- |
|  |  |  |

### Writing and erasing tags

Writes are started from the web UI but the device takes over the screen while one runs, showing `Writing NFC tag` / `Erasing NFC tag` with **Do not remove tag**.

| Writing | Erasing |
| --- | --- |
|  |  |

Take that literally. A write is not instant — an NTAG Extended write can take some seconds — and lifting the tag mid-write leaves it partially written. The status LED blinks blue for the whole operation, however long it takes.

Results are shown for a few seconds:

|  |  |  |
| --- | --- | --- |
| **Tag written** — complete success; the format used is named underneath | **ID only** — the tag was too small for the chosen format, so only the spool ID was stored | **Write failed** — the reason is shown (auth failure, tag removed, verify mismatch) |

|  |  |  |
| --- | --- | --- |
| **Tag erased** — erase completed | **Erase failed** — no tag present, or the erase errored | **Error** — any other flow step failing; the cause is named |

**ID only** is a warning, not a failure. The tag will still resolve to the right spool, but the extra fields are not on it — the database supplies them instead.

### Status LED and buzzer

The status LED is two WS2812 driven as one: one on the ESP32-S3 board, one on the enclosure top. They always show the same status.

The patterns below animate — the timings are the firmware's own, so what you see here is what the device does.

#### Resting and connection states

|  |  |  |
| --- | --- | --- |
| **Breathing green** — connected and idle, the normal resting state. Deliberately faint so an event flash stands out against it. | **Solid blue** — booting, or still joining the saved WiFi network. | **Solid orange** — no network reachable; the `OctoScale-Setup` portal is open. |

#### Busy — do not interrupt

|  |  |  |
| --- | --- | --- |
| **Blinking blue, 1 s** — software update running. Do not power off. | **Blinking blue, 0.5 s** — tag write, erase, or raw dump. Do not remove the tag. | **Solid cyan** — database lookup in flight. |

#### Event flashes

|  |  |  |
| --- | --- | --- |
| **Green** — spool recognised, or write succeeded. | **Amber** — write succeeded but fields were dropped (the **ID only** case). | **Red** — write failed, no printer configured, or a missing reference weight. |

Blue always means *do not interrupt*. Brightness for both WS2812 is a single slider in the web UI (System → Status LED); it scales the level only, never the colours or patterns.
The ESP32-S3's onboard WS2812 can be disabled in the web UI (System → Status LED).

The buzzer tones are matched to the LED, which blinks in lockstep with each tone segment. Frequencies and durations below are exactly what the firmware plays.

| | |
| --- | --- |
|  | Tag detected — the lightest signal, just "something happened". |
|  | OK, and the web UI's test tone. |
|  | Spool loaded or weight saved — two rising beeps. |
|  | Unknown spool or database offline — a low double tone. |

The buzzer can be switched off entirely in the Device menu or web UI (System → Buzzer); Volume is adjustable there as well.
The LED timing stays the same either way.

## Web UI user guide

Open `http://<device-ip>/`. The interface is six tabs; the device only polls for data belonging to the tab you are actually looking at, and stops entirely when the browser tab is hidden.

| Tab | Purpose |
| --- | --- |
| **Operate** | Live weight, tare, and the current spool |
| **NFC** | Read, write, and erase tags; raw dump for unknown tags |
| **Scale** | Calibration and HX711 diagnostics |
| **Setup** | OctoPrint instances, spool database selection, WiFi |
| **System** | Display, LED, buzzer, themes, firmware update, config backup |
| **Debug** | Live NFC and HTTP log |

### Operate

Live weight with a tare button, mirroring the device's idle screen. Use this to confirm a reading without walking to the device.

### NFC

**Write ID to tag** is the common case: it writes the spool ID in the format chosen for that tag type. Everything else on the tag is optional — the database remains the source of truth.

Two results are worth understanding:

- **`droppedFields`** — the data did not fit on this tag. Expected on small tags; the spool still resolves.
- **`unsupportedFields`** — the chosen format has no representation for that field at all. Changing tags will not help; changing format might.

**Raw dump** reads a tag sector by sector without interpreting it, which is what to reach for when a tag reads as unknown and you need to know whether it holds data at all.

### Scale

One-point calibration needs a single known reference weight. Two-point calibration uses a light and a heavy reference and checks linearity, which catches a load cell mounted under strain.

The calibration factor lives in NVS and survives reboots and OTA updates. The HX711 panel shows chip readiness, the raw ADC value, and noise; unstable noise here is a wiring or supply problem, not a calibration problem.

### Setup

Add each OctoPrint instance with name, host, port, and API key (OctoPrint → Settings → API), then select which instance holds the spool database. Instances sharing an external database can fail over for each other; instances on local SQLite cannot, since each has its own separate records.

### System

Display brightness and the three idle timeouts, LED brightness, buzzer mode, and both themes. Firmware updates can be uploaded directly or pulled from a URL.

Configuration backup exports as AES-256-CBC encrypted JSON. API keys are never written in plaintext, so a backup file is safe to keep off the device — but it is also unreadable without the passphrase, so store that somewhere durable.

The file covers the whole configuration: the calibration factor, every OctoPrint instance with its database selection and selection timeout, and all device settings — display brightness and the three idle timeouts, the screensaver, both themes, buzzer mode, volume and pitch, LED brightness and routing, the debug console, and the online firmware check. Restoring applies them immediately; no reboot is needed. A setting you have never changed is left out of the file rather than exported at its current default, so restoring an old backup onto newer firmware keeps that firmware's defaults instead of freezing yesterday's. For the same reason, a backup written before a setting existed simply leaves it alone. WiFi credentials are the one exception — WiFiManager stores them separately and they are not part of the file, so a restored device still needs its network set up.

**Restart device** reboots the hardware. Nothing is cleared: calibration, printers, API keys and every setting live in NVS and survive it — including the zero point, which is checked against a fresh reading on the way up rather than re-measured blindly. Restarting with a spool on the scale is therefore safe: the device reports the zero point as unverified and refuses to save a weight until you tare it, instead of quietly treating that spool as zero. It is refused while a firmware update is running, since a restart there would leave an incomplete image in the flash partition. The device is unreachable for roughly twenty seconds; the page reconnects on its own once it answers again, so no reload is needed. A weighing or tag write that happens to be in flight is lost — the spool weight in the database is not, because it is written before the tag is.

### Debug

A live log of NFC reads and HTTP calls. This polls at a high rate and only runs while the Debug tab is open and the browser tab visible, so leaving it open in a background window costs nothing. **Backlight trace** adds the display state every 10 s; it needs the log switched on and is off again after a restart.

## Troubleshooting

### The device reboots on its own

Almost always the power supply path, not the firmware. Check in this order:

1. **Are all three capacitors fitted?** 470 µF at the PN5180, 1500 µF at the ESP32-S3 `5V` pin, 100 µF at the Mini-360 output. The 470 µF one is what lets the PN5180 raise an RF field at all; the other two absorb WiFi transmit bursts. See the [Assembly Guide](Assembly-Guide).
2. **Is anything chained into the 5 V path?** USB switches, power meters, and extension cables each add contact resistance. A supply that measures a healthy 5 V at idle can still collapse under a current burst. Short, thick, and direct.
3. **Check the reset reason** in the Debug tab. A brownout and a firmware fault look identical from the outside but report differently — the [Development Guide](Development-Guide) explains how to read it.

### A tag is not recognised

The message on screen distinguishes the cases, and they have different fixes:

|  |  |
| --- | --- |
| **Unknown spool** — the tag was read fine, but its ID is not in the database. Assign the spool in SpoolManagerExtended, or write a fresh ID. | **No printer** — a spool resolved, but no OctoPrint instance is configured. Add one in the web UI under Setup. |

| Message | Meaning | Fix |
| --- | --- | --- |
| **Unknown spool** | The tag was read fine, but its ID is not in the database | Assign the spool in SpoolManagerExtended, or write a fresh ID |
| **Unreadable tag** | Data was found but no supported format could parse it | Check the raw dump; the tag may be foreign or partially written |
| No reaction at all | The tag was never detected | Reposition it, then check **NFC debug** or the NFC test |

A tag that reads intermittently by position is usually the 470 µF capacitor missing or too far from the PN5180.

### Weight is wrong or negative

- **Negative when loaded** — the load cell wires are swapped. Exchange white and green at the HX711.
- **Shows a weight with nothing on it, or the Scale tab says the zero point is unverified** — the reading no longer matches the stored zero point, and the device is showing you that rather than hiding it. The usual cause is a restart while something was on the scale; removing a holder that was part of the zero point does the same. Clear the scale and press **Tare**. Saving a weight is blocked until you do, so nothing wrong reaches the database or your tags in the meantime.
- **Drifting or noisy** — check the HX711 noise value in the Scale tab. Steady noise with a stable supply points at a mechanical problem: the load cell must be able to flex freely, bolted at one end only.
- **Consistently off by a factor** — recalibrate, preferably two-point.

### Nothing on the database side works

Weighing, taring, calibration, and reading, writing, and erasing tags all work without OctoPrint. Lookup, printer and tool selection, and weight updates need [OctoPrint-SpoolManagerExtended](https://github.com/Ajimaru/OctoPrint-SpoolManagerExtended) reachable and configured with a valid API key. Check the DB indicator in the idle footer and the spool-ID lookup test in Setup.

### The encoder turns the wrong way

Swap `A` and `B` on the encoder. Confirm with the Knob test.

### The web UI is unreachable

Check the device's System info screen for its IP; the router may have issued a new one. Use the IP rather than `octoscale.local` — mDNS is unreliable here, and it is also why OTA updates should be addressed by IP.

---

For implementation details, the HTTP API, and the tag format internals, continue with the [Development Guide](Development-Guide).

<!-- markdownlint-enable MD033 -->

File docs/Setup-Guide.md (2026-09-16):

# OctoScale Setup Guide

This guide covers the first firmware flash, OTA updates, and first-time device setup. Start with the [Assembly Guide](Assembly-Guide) if the hardware is not assembled yet.

## Build & flash

Install [PlatformIO](https://platformio.org/). The patched PN5180 library is vendored in `lib/`; other dependencies are downloaded from `lib_deps` on the first build.

For the first flash, disconnect the external 5 V supply and connect USB:

```bash
pio run -e esp32s3 -t upload
```

On first boot, connect to the `OctoScale-Setup` access point, enter WiFi credentials, and note the assigned IP from the router or serial monitor:

```bash
pio device monitor -e esp32s3
```

The web UI is at `http://<device-ip>/`. Later firmware updates use OTA and do not need USB:

```bash
pio run -e esp32s3_ota -t upload --upload-port <device-ip>
```

Use the IP address for OTA rather than `octoscale.local` because mDNS can make `espota` time out.

### Prebuilt firmware files

Tagged releases provide ready-to-use firmware files under [GitHub Releases](https://github.com/Ajimaru/OctoScale/releases):

- `octoscale-usb.bin` is the merged image for a first USB flash. Flash it at address `0x0` with an ESP32-S3 tool such as `esptool`.
- `octoscale-ota.bin` is the application image for an OTA update through the web UI or the `/updateurl` endpoint. Do not use it for the first flash; it does not contain the bootloader and partition table.

Release artifacts are created when a tag such as `v0.0.1` matches `FW_VERSION` in `src/version.h`. The GitHub Actions firmware artifact is intended for CI inspection; the tagged GitHub Release is the stable download location.

## First-time setup

Open `http://<device-ip>/` and work through these steps in order.

1. **Calibrate.** Click on the Scale tab, then empty the scale and tare it. Use a known reference weight with either one-point calibration or two-point calibration using light and heavy references. Verify the result. The HX711 diagnostics panel shows chip readiness, raw ADC value, and noise; unstable noise usually indicates wiring or supply trouble.
2. **Add printers.** In the Setup tab, add each OctoPrint instance with name, host, port, and API key from OctoPrint Settings > API.
3. **Choose the spool database.** Select the OctoPrint instance used for spool records. Instances sharing an external database can fail over; local SQLite instances cannot. Use the spool-ID lookup test.
4. **Review optional settings.** Configure selection timeout in the Setup Tab, display brightness and idle stages, LED brightness, buzzer mode/tones in the System tab, and web/display themes.
5. **Test a spool.** Put a tagged spool on the scale. For a new tag, use NFC > Write ID to tag. The Debug tab can log reads and lookups.

### Software requirement

Database features require [OctoPrint-SpoolManagerExtended](https://github.com/Ajimaru/OctoPrint-SpoolManagerExtended). OctoScale uses its API endpoints for spool lookup by ID or UID, measured-weight updates, printer/tool loading, and database identification for failover. All calls use API keys; OctoScale never connects to MySQL directly.

Without the plugin, weighing, taring, calibration, reading, writing, and erasing NFC tags still work. Automatic lookup, printer/tool selection, and database weight updates do not.

Continue with the [User Guide](User-Guide) to operate the device, or consult the [Development Guide](Development-Guide) for implementation details.

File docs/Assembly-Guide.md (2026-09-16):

# OctoScale Assembly Guide

## Wiring

All pin numbers below are GPIO numbers and match `src/main.cpp`. The PN5180 and TFT use separate SPI buses.

### Wiring diagram

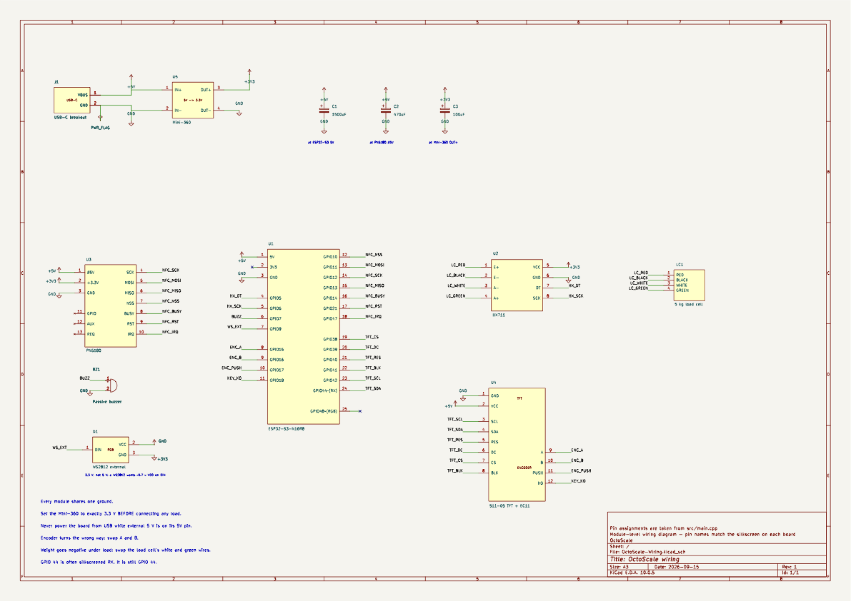
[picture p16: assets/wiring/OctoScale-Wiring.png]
OctoScale wiring schematic showing all modules, power rails and signal nets


Every pin in the diagram carries the name printed on the module itself, so a symbol can be compared against the board in hand without translating part numbers. Signals are joined by net labels rather than long lines: `NFC_SCK` at the ESP32-S3 and `NFC_SCK` at the PN5180 are the same wire.

The KiCad source is in [`hardware/OctoScale-Wiring/`](https://github.com/Ajimaru/OctoScale/tree/main/hardware/OctoScale-Wiring) along with the module symbol library; the schematic passes ERC with no errors or warnings.

### Power

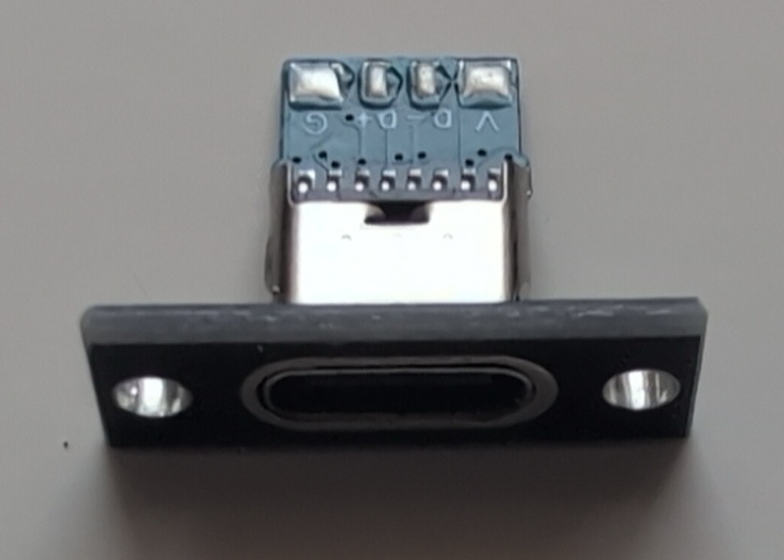
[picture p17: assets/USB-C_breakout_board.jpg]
USB-C breakout board
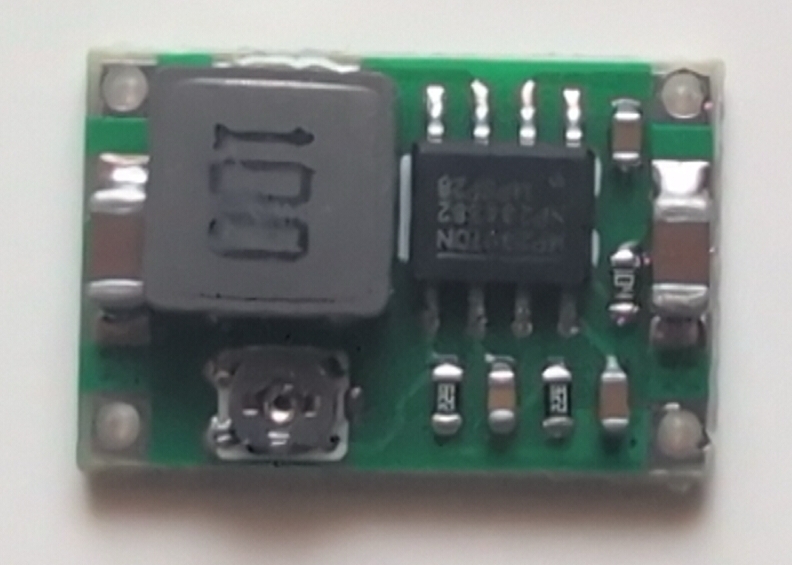
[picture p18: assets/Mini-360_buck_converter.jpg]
Mini-360 buck converter
 

Power enters through the USB-C breakout. The 5 V rail powers the ESP32-S3, PN5180 RF section, and TFT. The Mini-360 converts 5 V to 3.3 V for the HX711, PN5180 logic, and external WS2812. Everything shares one ground.

Before connecting any load, feed the Mini-360 with 5 V and adjust `OUT+` to exactly 3.3 V with a multimeter.

Then fit the three electrolytic capacitors. All mount with short leads directly at the points they buffer — a few centimetres of wire undoes most of the benefit — and all are polarised, so check the negative stripe before powering up.

| Capacitor | Across | Purpose |
| --- | --- | --- |
| 470 uF | PN5180 `#5V` and `GND` | RF field current spikes |
| 1500 uF | ESP32-S3 `5V` and `GND` | WiFi transmit bursts |
| 100 uF | Mini-360 `OUT+` and `GND` | the 3.3 V rail (HX711, PN5180 logic) |

The 470 uF one is what lets the PN5180 raise an RF field at all; without it the reader only detects tags sporadically. The other two keep the supply steady under load. Note the third sits at the **converter output**, not at the ESP32-S3's `3V3` pin — that pin is an output of the board's own regulator and feeds nothing here.

> [!WARNING]
> Never power the ESP32-S3 from USB while external 5 V is connected to its `5V`/`VBUS`/`VIN`
> pin. Disconnect the external supply for the first USB flash and any later recovery flash.

### Signal wiring

| Component | Pin | ESP32-S3 / rail |
| --- | --- | --- |
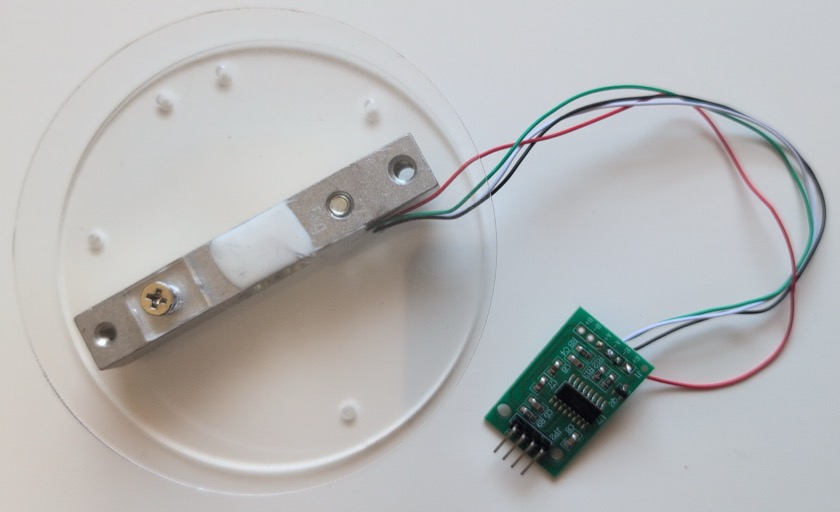
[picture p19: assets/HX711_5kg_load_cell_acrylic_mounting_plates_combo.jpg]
Load cell preview
| Load cell<br> | red / black / white / green | HX711 `E+` / `E-` / `A-` / `A+` |
| HX711<br><a href="https://raw.githubusercontent.com/Ajimaru/OctoScale/main/assets/HX711_5kg_load_cell_acrylic_mounting_plates_combo.jpg">HX711 preview</a> | `VCC`, `GND`, `DT`, `SCK` | 3.3 V, GND, GPIO 5, GPIO 6 |
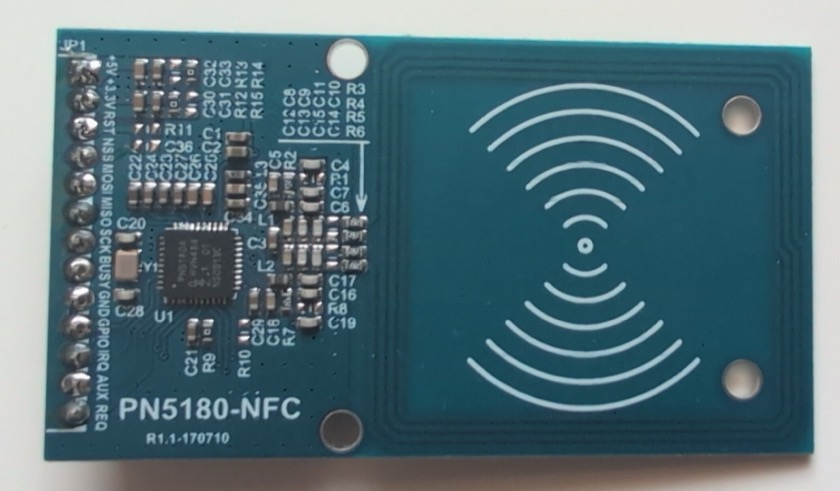
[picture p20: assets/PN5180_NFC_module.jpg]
PN5180 preview
| PN5180<br> | `+5V`, `+3.3V`, `GND` | 5 V, 3.3 V, GND |
| PN5180<br><a href="https://raw.githubusercontent.com/Ajimaru/OctoScale/main/assets/PN5180_NFC_module.jpg">PN5180 preview</a> | `SCK`, `MOSI`, `MISO`, `NSS` | GPIO 12, 11, 13, 10 |
| PN5180<br><a href="https://raw.githubusercontent.com/Ajimaru/OctoScale/main/assets/PN5180_NFC_module.jpg">PN5180 preview</a> | `BUSY`, `RST`, `IRQ` | GPIO 14, 21, 47 |
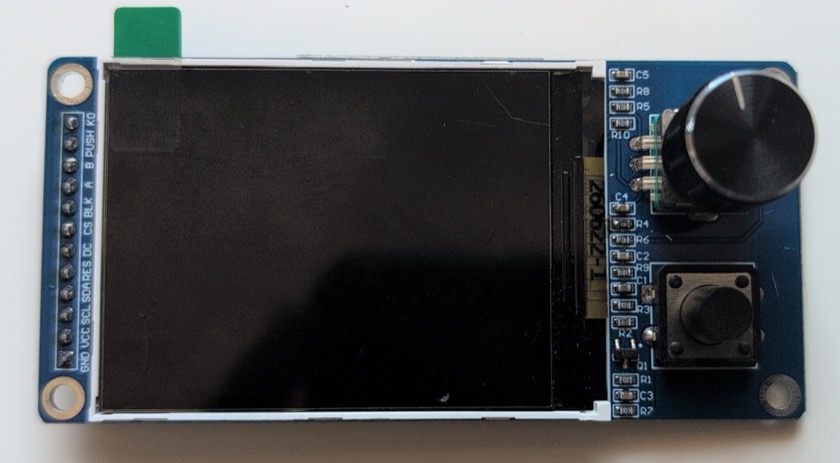
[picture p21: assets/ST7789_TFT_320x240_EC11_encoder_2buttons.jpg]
TFT and encoder preview
| TFT/encoder module<br> | `VCC`, `GND` | 5 V, GND |
| TFT<br><a href="https://raw.githubusercontent.com/Ajimaru/OctoScale/main/assets/ST7789_TFT_320x240_EC11_encoder_2buttons.jpg">TFT preview</a> | `SCL`, `SDA`, `CS`, `DC`, `RES`, `BLK` | GPIO 42, 44, 38, 39, 40, 41 |
| Encoder/buttons<br><a href="https://raw.githubusercontent.com/Ajimaru/OctoScale/main/assets/ST7789_TFT_320x240_EC11_encoder_2buttons.jpg">Encoder and buttons preview</a> | `A`, `B`, `PUSH`, `KO` | GPIO 15, 16, 17, 18; other switch legs to GND |
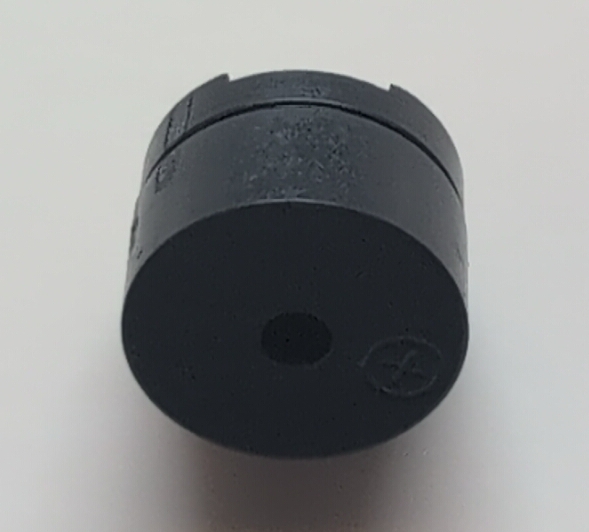
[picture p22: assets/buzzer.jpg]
Passive buzzer preview
| Buzzer<br> | `+`, `-` | GPIO 7, GND |
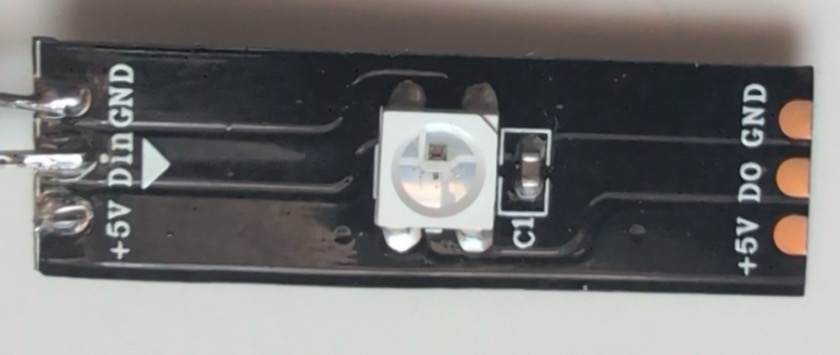
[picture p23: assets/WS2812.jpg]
WS2812 preview
| External WS2812<br> | `DIN`, `VCC`, `GND` | GPIO 9, 3.3 V, GND |

GPIO 44 is often labelled `RX`; it is still GPIO 44. If encoder rotation is reversed, swap `A` and `B`. If weight becomes negative when loaded, swap the load-cell white and green wires. PN5180 `GPIO`, `AUX`, and `REQ` remain unconnected.

## Enclosure

Mounting order is printed part, board, spacer, screw. Component names are embossed on the printed parts. The external WS2812 has no dedicated seat: solder its wires, test it, then glue it inside `OctoScaleLit.stl` behind the front opening. Use transparent filament for `OctoScaleLEDCover.stl`; sparse infill makes the diffuser cloudy.

Continue with the [Setup Guide](Setup-Guide) for build, flash, and first-time configuration.

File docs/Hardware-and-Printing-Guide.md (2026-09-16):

<!-- markdownlint-disable MD033 -->

# OctoScale Hardware & Printing Guide

This guide lists the hardware to buy and the printed parts to produce before assembly. Continue with the [Assembly Guide](Assembly-Guide) when the parts are ready.

## Hardware BOM

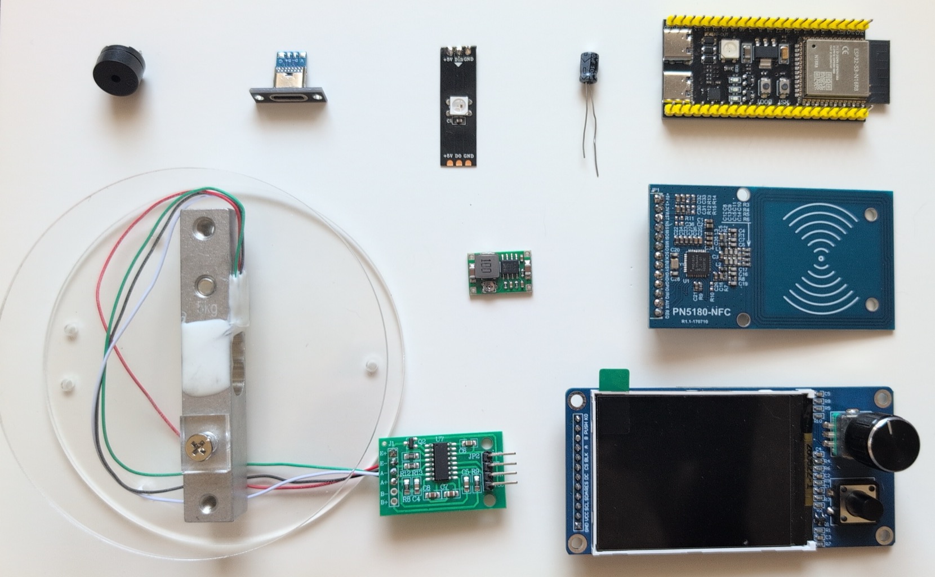
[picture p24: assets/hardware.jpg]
All OctoScale hardware components laid out


| Qty | Part | Notes |
| --- | --- | --- |
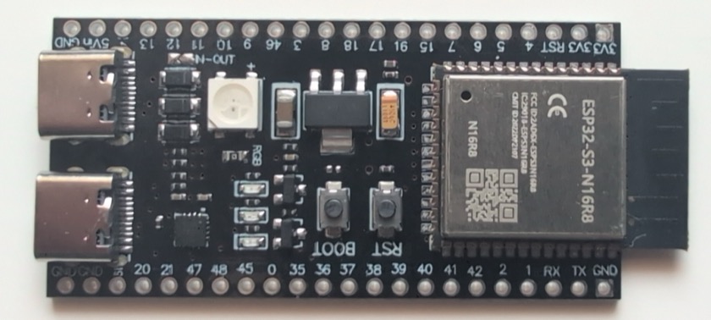
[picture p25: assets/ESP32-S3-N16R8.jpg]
ESP32-S3-N16R8 preview
| 1 | ESP32-S3-N16R8 (YD-ESP32-S3 / DevKitC-1)<br> | 16 MB flash, 8 MB octal PSRAM; R8/OPI variant is the reference board |
| 1 | HX711 ADC breakout<br><a href="https://raw.githubusercontent.com/Ajimaru/OctoScale/main/assets/HX711_5kg_load_cell_acrylic_mounting_plates_combo.jpg">HX711 preview</a> | 24-bit load-cell amplifier |
| 1 | 5 kg load cell<br><a href="https://raw.githubusercontent.com/Ajimaru/OctoScale/main/assets/HX711_5kg_load_cell_acrylic_mounting_plates_combo.jpg">5 kg load cell preview</a> | Straight bar type with acrylic mounting plates |
| 1 | PN5180 NFC module<br><a href="https://raw.githubusercontent.com/Ajimaru/OctoScale/main/assets/PN5180_NFC_module.jpg">PN5180 preview</a> | Supports NFC-A and NFC-V/OpenPrintTag |
| 1 | ST7789 TFT 320x240 with EC11 encoder and 2 buttons<br><a href="https://raw.githubusercontent.com/Ajimaru/OctoScale/main/assets/ST7789_TFT_320x240_EC11_encoder_2buttons.jpg">TFT and encoder preview</a> | S11-05 combo module |
| 1 | Passive buzzer<br><a href="https://raw.githubusercontent.com/Ajimaru/OctoScale/main/assets/buzzer.jpg">Passive buzzer preview</a> | Driven by LEDC PWM |
| 1 | 470 uF electrolytic capacitor, 10 V+ | Mandatory; install at the PN5180 5 V input |
| 1 | 1500 uF electrolytic capacitor, 10 V+ | Mandatory; buffers the ESP32-S3 board's 5 V pin |
| 1 | 100 uF electrolytic capacitor, 16 V+ | Mandatory; buffers the Mini-360 output (3.3 V rail) |
| 1 | USB-C power supply | 5 V, at least 1.5 A |
| 1 | USB-C breakout board<br><a href="https://raw.githubusercontent.com/Ajimaru/OctoScale/main/assets/USB-C_breakout_board.jpg">USB-C breakout preview</a> | Main 5 V entry point |
| 1 | Mini-360 buck converter<br><a href="https://raw.githubusercontent.com/Ajimaru/OctoScale/main/assets/Mini-360_buck_converter.jpg">Mini-360 buck converter preview</a> | Adjust output to 3.3 V before connecting loads |
| 1 | WS2812 RGB LED module<br><a href="https://raw.githubusercontent.com/Ajimaru/OctoScale/main/assets/WS2812.jpg">WS2812 preview</a> | External enclosure status LED |
| 10 | ST2.9 self-tapping screws, about 9.7 mm | Mount printed parts; no heat-set inserts |
| 2 | ST2.2 self-tapping screws, about 6 mm | Mount the USB-C breakout |

Reference photos are available in `assets/` (`hardware.jpg`, `ESP32-S3-N16R8.jpg`, and the component photos). The printed parts are listed below; wiring and assembly are covered in the [Assembly Guide](Assembly-Guide).

## Printed parts

Printable parts are in `stl_files/`:

| File | Qty | Part | Settings |
| --- | --- | --- | --- |
| [<code>OctoScale_Top.stl</code>](https://github.com/Ajimaru/OctoScale/blob/main/stl_files/OctoScale_Top.stl)<br><br>Preview of OctoScale top plate | 1 | Top plate; spool rests here; PN5180 below | 0.2 mm layers, 0.25 mm first layer, 15% infill |
| [<code>OctoScaleBottom.stl</code>](https://github.com/Ajimaru/OctoScale/blob/main/stl_files/OctoScaleBottom.stl)<br><br>Preview of OctoScale bottom | 1 | Base for HX711 ADC breakout, ESP32-S3, Mini-360 buck converter and USB-C breakout board | Same |
| [<code>OctoScaleLit.stl</code>](https://github.com/Ajimaru/OctoScale/blob/main/stl_files/OctoScaleLit.stl)<br><br>Preview of OctoScale front lid | 1 | Front lid for ST7789 TFT display and WS2812 RGBstatus LED | Same |
| [<code>OctoScaleScreenBazel.stl</code>](https://github.com/Ajimaru/OctoScale/blob/main/stl_files/OctoScaleScreenBazel.stl)<br><br>Preview of OctoScale display bezel | 1 | Display bezel, 64 x 47 x 1.6 mm | Same |
| [<code>OctoScaleKnobCover.stl</code>](https://github.com/Ajimaru/OctoScale/blob/main/stl_files/OctoScaleKnobCover.stl)<br><br>Preview of OctoScale knob cover | 1 | EC11 knob cover, 13.5 mm diameter, 5.2 mm tall | Same |
| [<code>OctoScaleButtonCover.stl</code>](https://github.com/Ajimaru/OctoScale/blob/main/stl_files/OctoScaleButtonCover.stl)<br><br>Preview of OctoScale button cover | 1 | Button cover, 13.5 mm diameter, 1.8 mm tall | Same |
| [<code>OctoScaleSpacer.stl</code>](https://github.com/Ajimaru/OctoScale/blob/main/stl_files/OctoScaleSpacer.stl)<br><br>Preview of OctoScale spacer | 10 | 5.5 x 5.5 x 3.5 mm screw spacer | Same |
| [<code>OctoScaleLEDCover.stl</code>](https://github.com/Ajimaru/OctoScale/blob/main/stl_files/OctoScaleLEDCover.stl)<br><br>Preview of OctoScale LED cover | 1 | 7 x 7 x 1.4 mm light window | Transparent filament, 99.99% infill |

When everything is available, continue with the [Assembly Guide](Assembly-Guide).

<!-- markdownlint-enable MD033 -->

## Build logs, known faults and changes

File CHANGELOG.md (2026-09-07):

# Changelog

Changes are documented in the GitHub release notes:

**[github.com/Ajimaru/OctoScale/releases](https://github.com/Ajimaru/OctoScale/releases)**

Each release lists what changed in that version. The version a device is running is
shown in the footer of its web UI, next to the build timestamp.

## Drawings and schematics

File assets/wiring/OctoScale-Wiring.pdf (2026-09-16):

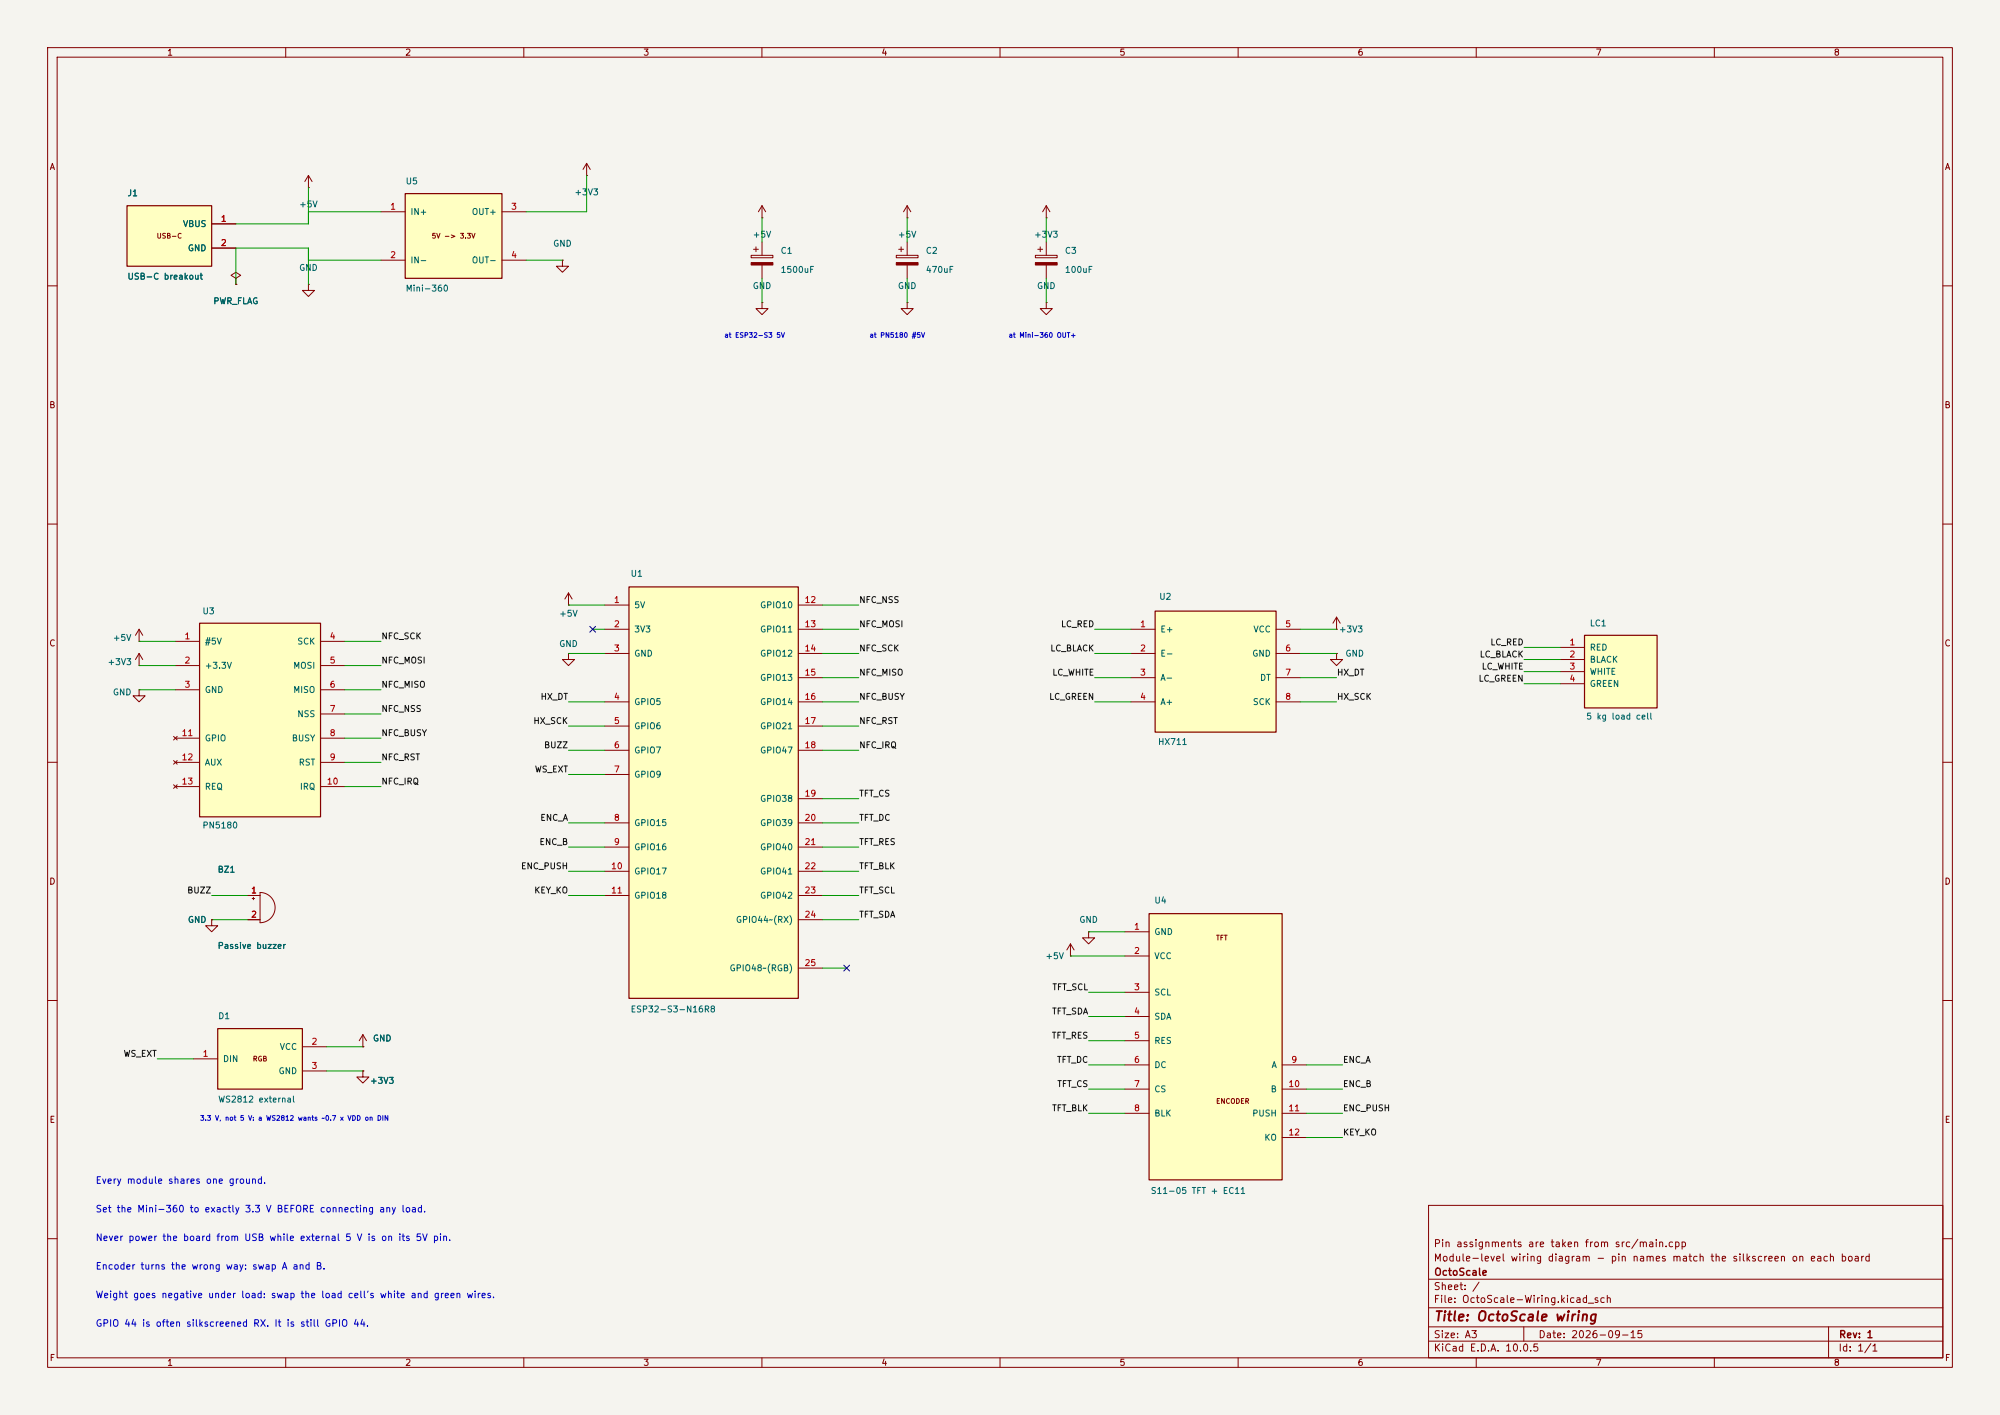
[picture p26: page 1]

LC_RED HX_DT
5 kg load cell GND

LC_BLACK NFC_MISO GPIO 44 is often silkscreened RX. It is still GPIO 44.
LC_WHITE WS_EXT

Never power the board from USB while external 5 V is on its 5V pin. Set the Mini-360 to exactly 3.3 V BEFORE connecting any load. Weight goes negative under load: swap the load cell's white and green wires. GND +3V3 GND

Every module shares one ground. 3.3 V, not 5 V: a WS2812 wants ~0.7 x VDD on DIN

Pin assignments are taken from src/main.cpp
Module-level wiring diagram - pin names match the silkscreen on each board
OctoScale
Sheet: /
File: OctoScale-Wiring.kicad_sch
Title: OctoScale wiring

Encoder turns the wrong way: swap A and B.

Size: A3 | Rev: 1 | F Date: 2026-09-15
KiCad E.D.A. 10.0.5 | Id: 1/1

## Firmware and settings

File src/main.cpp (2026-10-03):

// OctoScale — NFC filament scale for OctoPrint + SpoolManagerExtended
//
// Copyright (c) 2026 Ajimaru
//
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
#include <Arduino.h>
#include <WiFi.h>
#include <WiFiManager.h>       // tzapu/WiFiManager
#include <WebServer.h>
#include <ESPmDNS.h>
#include <ArduinoOTA.h>
#include <Update.h>
#include <HTTPClient.h>
#include <HTTPUpdate.h>       // URL-based OTA (/updateurl)
#include <WiFiClientSecure.h>
#include <HX711.h>
#include <Preferences.h>
#include <Adafruit_NeoPixel.h>
#include <esp_chip_info.h>     // chip model/revision/cores for /system
#include <esp_idf_version.h>   // IDF version string for /system
#include <esp_ota_ops.h>       // OTA partition size for /system
#include <hal/brownout_hal.h>  // raise BOD threshold, see raiseBrownoutThreshold()

// OctoScale (ESP32-S3) — WiFi provisioning (AP fallback) + OTA + HX711 scale +
// PN5180 NFC (SPI) + ST7789 TFT menu + EC11 encoder + buzzer.

#include "dbglog.h"     // in-RAM debug log ring buffer (web UI console, see /debuglog)
#include "version.h"    // FW_VERSION, FW_BUILD
#include "web_ui.h"     // INDEX_HTML (web UI HTML/CSS/JS)
#include "octoprint.h"  // OctoPrint instances + tool count/load URL/spool info
#include "spooldb.h"    // spoolExists() via the SpoolManagerExtended HTTP bridge (DB source)
#include "backup.h"     // config backup/restore (AES-encrypted API keys)
#include "display.h"    // ST7789 TFT
#include "pn5180nfc.h"  // PN5180 NFC reader (SPI)
#include "openprinttag.h"  // OpenPrintTag (OPT) read/write, NFC-V only
#include "encoder.h"    // EC11 encoder + buttons

const char *AP_NAME = "OctoScale-Setup";  // SoftAP when no WiFi is configured
const char *HOSTNAME = "octoscale";        // mDNS: octoscale.local

// --- ESP32-S3-N16R8 (dual-core), full build. Only target of this project. ---
// AVOIDED: strapping 0/3/45/46, USB 19/20, octal PSRAM+flash 26-37 (R8/N16!).
// Peripherals: HX711 (scale), PN5180 (NFC over SPI), ST7789 TFT (SPI), EC11 encoder +
// start button, buzzer, onboard RGB LED (GPIO48).
const int LED_PIN = 2;         // free GPIO used as a status LED
const int HX711_DOUT = 5;
const int HX711_SCK = 6;
const int WS2812_PIN = 48;     // onboard RGB LED (WS2812)
// External WS2812 on the enclosure front. The onboard LED at GPIO48 sits under the
// housing where its color isn't readable, so a second pixel mirrors it 1:1 to the
// outside. Own GPIO rather than chained into GPIO48's data-out: that pad isn't
// broken out on the DevKitC. GPIO 9 is free, not a strapping pin and has no boot
// function; 8 stays reserved for a possible I2C, 43 is U0TXD (the CH343 console).
// Powered from the 3.3V rail (Mini-360), NOT 5V: a WS2812 wants ~0.7 x VDD on DIN, so
// at 5V it expects 3.5V while the S3 drives 3.3V -- works on the bench but is out of
// spec. On 3.3V the level is exact. Module carries its own series resistor, no cap.
const int WS2812_EXT_PIN = 9;

// PN5180 and TFT have SEPARATE SPI buses. Sharing one bus caused the PN5180 to stop
// reading tags after the TFT init (the GPIO matrix only lets one controller cleanly
// drive shared pins). Hence:
//   PN5180 (FSPI, global SPI instance): SCK=12, MOSI=11, MISO=13
//   TFT    (HSPI, TFT_eSPI):            SCK=42, MOSI=44 (in platformio.ini), MISO unused
const int SPI_SCK  = 12;   // PN5180 bus (FSPI)
const int SPI_MOSI = 11;
const int SPI_MISO = 13;
// PN5180 (NFC, SPI) — NFC-A + NFC-V. Module labels: #5V/+3.3V/GND/SCK/MOSI/MISO/NSS/
// BUSY/RST/IRQ (GPIO/AUX/REQ unused -> left open).
const int PN5180_NSS  = 10;    // module "NSS" — chip select (active low)
const int PN5180_BUSY = 14;    // module "BUSY" — status (input)
const int PN5180_RST  = 21;    // module "RST" — reset (active low)
const int PN5180_IRQ  = 47;    // module "IRQ"
// Module S11-05: ST7789 TFT (2.4" 320x240, 4-wire SPI) + EC11 encoder + buttons on ONE
// connector: GND VCC SCL SDA RES DC CS BLK A B PUSH KO. SCL=SPI clock, SDA=MOSI
// (write-only, no MISO). The TFT pins themselves come as TFT_eSPI macros from
// platformio.ini (-DTFT_CS/DC/RST/BL) — these are documentation-only constants
// (prefixed TFTPIN_ to avoid a macro collision).
const int TFTPIN_CS  = 38;     // module "CS"  (== -DTFT_CS)
const int TFTPIN_DC  = 39;     // module "DC"  (== -DTFT_DC)
const int TFTPIN_RST = 40;     // module "RES" (== -DTFT_RST)
const int TFTPIN_BLK = 41;     // module "BLK" — backlight (== -DTFT_BL)
// Encoder + buttons (internal pull-ups, other side to GND).
const int ENC_A   = 15;        // module "A" — encoder rotation
const int ENC_B   = 16;        // module "B" — encoder rotation
const int ENC_SW  = 17;        // module "PUSH" — encoder click
const int KEY_START = 18;      // module "KO" — separate start button
const int BUZZER_PIN = 7;      // signal buzzer (+ on GPIO 7, - to GND); GPIO 2 = LED_PIN

// Neutral placeholder, NOT a real load-cell factor (that was specific to a previous
// scale) -> just needs to be a safe non-zero divisor until the user calibrates.
const float DEFAULT_CALIBRATION_FACTOR = 1.0;
// Tag layout of the databaseId (NFC-A/NTAG pages or NFC-V blocks) is encapsulated in
// pn5180nfc.h (PN5180_ID_START_PAGE / PN5180_ID_START_BLOCK / PN5180_ID_BYTES).

WebServer server(80);
HX711 scale;
Preferences prefs;  // NVS storage for the calibration factor
Adafruit_NeoPixel pixel(1, WS2812_PIN, NEO_GRB + NEO_KHZ800);  // 1x WS2812 status LED
// Mirrors `pixel` exactly -- never driven independently. Every write goes through
// ledShow() so both strands stay in lockstep and share the RMT lock (see ledShow()).
Adafruit_NeoPixel pixelExt(1, WS2812_EXT_PIN, NEO_GRB + NEO_KHZ800);

volatile float g_weight = 0.0;  // latest weight (g), updated by loop()
// Tare request: the web UI (/tare) and the TFT menu only set this flag. scale.tare()
// blocks ~1s and shares the HX711 with scaleTask -> the task consumes the flag and
// tares itself (no concurrent HX711 access from two tasks). Cross-task -> volatile.
volatile bool g_tareReq = false;

// CPU load approximation (loop task), averaged over a 1s window.
unsigned long g_cpuBusyAccum = 0;   // accumulated busy-us in the current window
unsigned long g_cpuWinStart = 0;    // window start time (millis)
volatile uint8_t g_cpuLoad = 0;     // 0-100%, last window's load (loop approximation)

// ---- Dual-core load (idle-counter method) --------------------------------
// FreeRTOS runtime stats aren't enabled in the Arduino core (no menuconfig).
// Alternative: one lowest-priority task per core that counts up and yields in a loop
// -> it only gets CPU when nothing else wants to run (= idle). If the counting rate
// falls below a calibrated idle baseline, the core is busy.
// load% = 100 - (rate / baseline * 100). Baseline = the highest rate ever seen/core.
volatile uint32_t g_idleCtr[2] = {0, 0};       // raw idle counter per core
uint32_t g_idleBaseline[2] = {1, 1};           // calibrated idle rate/s per core
volatile uint8_t g_coreLoad[2] = {0, 0};       // 0-100% per core
static void idleCounterTask(void *arg) {
  int core = (int)(intptr_t)arg;
  for (;;) { g_idleCtr[core]++; taskYIELD(); }
}
float g_calFactor = DEFAULT_CALIBRATION_FACTOR;  // active factor (loaded from NVS)
bool g_scaleReady = false;

// ---- Zero-point trust -------------------------------------------------------------
// The tare offset used to be a pure runtime value: every boot re-tared blindly
// (startScale()) and therefore adopted whatever happened to be sitting on the scale.
// With a spool on it -- the normal state after a brownout reset, and raiseBrownoutThreshold()
// below deliberately makes those resets MORE likely so they become diagnosable -- that
// spool's weight became the new zero. Nothing about that was visible afterwards: scaleTask
// clamps the resulting negative readings to 0, so the empty scale read a perfectly
// plausible "0.0 g" and the error only surfaced once it had been written to the database
// and onto the tag, neither of which has a way back.
//
// So: persist the offset AND check it at boot instead of reinventing it.
//
// What this state deliberately does NOT claim matters as much as what it does. When the
// boot reading deviates strongly from the stored offset, a SINGLE measurement cannot
// distinguish "a load is sitting on it" from "the cell drifted over weeks" from "somebody
// rebuilt the mechanics". The firmware therefore reports only the observation it can back
// up ("zero point deviates by X g") and refuses the unprovable conclusion -- it names no
// cause. Hence ZERO_SUSPECT, not ZERO_LOAD_ON_BOOT.
enum ScaleZeroState : uint8_t {
  ZERO_OK = 0,      // boot reading agrees with the stored offset
  ZERO_UNVERIFIED,  // no comparable offset stored (first boot / factor changed)
  ZERO_SUSPECT,     // deviation too large -> stored offset kept, NOT re-tared
  ZERO_UNSTABLE,    // boot reading too restless to support any statement
};
// Written by scaleTask (core 0) and startScale(), read by the HTTP handlers (core 1) ->
// volatile, like the other scale diagnostics. Note that g_scaleZeroState and
// g_scaleZeroDelta are NOT atomic together: a /scaleinfo poll can catch a state that has
// just changed next to a delta that has not. That is harmless -- the delta is display
// only, and the write-guard reads nothing but the state. Please don't "fix" it with a
// mutex; the cure would cost more than the disease.
volatile ScaleZeroState g_scaleZeroState = ZERO_UNVERIFIED;
volatile long  g_scaleZeroDelta = 0;      // boot reading minus stored offset, ADC counts
volatile long  g_scaleZeroStoredOff = 0;  // the offset that was loaded (0 = none), for /scaleinfo
volatile float g_scaleZeroNoise = 0.0f;   // std-dev of the boot window, ADC counts

// Thought of in grams and converted to counts at runtime (g_calFactor = counts/gram),
// because counts are device specific.
//
// Lower bound is the scale's own noise: 22-50 counts std-dev measured on the built unit,
// with the raw value wandering across a ~100-count band (see the derivation of
// SCALE_STUCK_TOLERANCE below). A threshold underneath that band would trip on every
// other boot for no reason.
//
// Upper bound is what still does no relevant damage: the lightest thing realistically
// left on the scale is an empty spool at ~150-250 g depending on make. The threshold has
// to stay well below that -- otherwise exactly the case this guards against slips through.
//
// 20 g sits comfortably between the two: far above the noise even with a weak factor, far
// below any load. Temperature drift of a 5 kg cell runs a few tenths of a percent of
// nominal across its operating range, which stays well under 20 g over the few degrees a
// device sees in a room; across weeks and larger swings it can wander there, which is why
// the OK case nudges the stored offset along (see scaleZeroEvaluate()).
static const float    SCALE_ZERO_TOL_G = 20.0f;
// Quiet criterion before an automatic tare. Same unit and same formula as noiseStdDev in
// /scaleinfo. Deliberately generous (3x the measured resting ceiling of ~50 counts):
// the only thing to rule out here is "somebody is touching the scale right now", not "this
// cell is slightly noisier than average" -- too strict a bound would permanently block
// boots on a poorly decoupled table.
static const float    SCALE_ZERO_STABLE_MAX_SD = 150.0f;
static const uint8_t  SCALE_ZERO_STABLE_SAMPLES = 10;    // same window size as /scaleinfo
static const uint32_t SCALE_ZERO_STABLE_TIMEOUT_MS = 3000;

// Tolerance in ADC counts. At DEFAULT_CALIBRATION_FACTOR (1.0, a neutral placeholder --
// see above) the device is not calibrated at all: "grams" carries no meaning there and a
// threshold derived from it would be numerology. Fall back to a plain noise multiple that
// holds without calibration.
static long scaleZeroTolCounts() {
  if (g_calFactor <= 0.0f || g_calFactor == DEFAULT_CALIBRATION_FACTOR) return 500;
  long t = (long)(SCALE_ZERO_TOL_G * g_calFactor);
  // Never below the measured resting band (~100 counts) x2: with a small factor (coarse
  // scale, few counts per gram) 20 g would land underneath the noise -> permanent alarm.
  if (t < 200) t = 200;
  return t;
}

// May a measured weight be written to the database and onto the tag?
//
// ZERO_UNVERIFIED is deliberately NOT blocked: that is the first boot of a freshly flashed
// device, and blocking there would prevent commissioning without covering any known
// failure -- the user calibrates and tares in that state anyway.
static bool scaleZeroTrusted() {
  return g_scaleZeroState == ZERO_OK || g_scaleZeroState == ZERO_UNVERIFIED;
}

// Zero-state names for the UI (order matches enum ScaleZeroState)
static const char *scaleZeroStateName(ScaleZeroState s) {
  switch (s) {
    case ZERO_OK:         return "ok";
    case ZERO_UNVERIFIED: return "unverified";
    case ZERO_SUSPECT:    return "suspect";
    case ZERO_UNSTABLE:   return "unstable";
    default:              return "unverified";
  }
}

// Deviation in grams, for messages and /scaleinfo. Guards the factor because an
// uncalibrated device divides by the 1.0 placeholder and would report counts as grams.
static float scaleZeroDeltaGrams() {
  return (g_calFactor > 0.0f) ? ((float)g_scaleZeroDelta / g_calFactor) : 0.0f;
}

// ---- HX711 diagnostics (/scaleinfo) -----------------------------------------------
// The HX711 itself has no status/health registers (unlike the PN5180) -- it's a bare
// 24-bit ADC. What's useful to surface instead: the raw (unscaled, untared) reading, so
// a stuck-near-full-scale value is visible as "ADC saturating" rather than just a wrong
// weight; whether the chip is currently answering ready() at all; and a noise estimate
// (std-dev over a short raw-reading window) as a proxy for wiring/load-cell health that
// the chip can't report directly but we can compute from what we already sample.
volatile long g_scaleRawLast = 0;        // most recent raw ADC reading (get_value(1), no smoothing)
volatile bool g_scaleHxReady = false;    // scale.is_ready() as of the last scaleTask iteration
volatile uint32_t g_scaleLastReadMs = 0; // millis() of the last successful HX711 read
#define SCALE_NOISE_WINDOW 10
volatile long g_scaleNoiseBuf[SCALE_NOISE_WINDOW] = {0};
volatile uint8_t g_scaleNoiseCount = 0;  // how many of the buffer's slots are filled (ramps up to WINDOW once)
// Stuck-HX711 watchdog. Symptom seen in the field: the scale stopped measuring and only
// came back after a full power cycle -- /scaleinfo showed raw == offset frozen and
// noiseStdDev exactly 0. That last part is the reliable signal: a real load cell always
// dithers by a few ADC counts (thermal + mains + quantisation), so ZERO variation over
// a whole window means no fresh conversion is arriving, not "a very steady weight".
//
// Explicitly NOT triggered by is_ready()==false: at 10 SPS polled every 20ms that is
// false most of the time by design (roughly 1 in 8 polls sees a sample), so resetting
// on it would re-init the chip several times a second.
volatile uint32_t g_scaleStuckSince = 0;    // millis() when raw last MOVED (0 = unknown yet)
// "Moved" means: away from the value the current stuck-window started at, by more than
// this many ADC counts. NOT plain inequality against the previous sample: at rest the
// dither is only a few counts wide, so it repeats a value now and then and sits there
// for seconds -- which a != check reads as "frozen" and power-cycles a perfectly healthy
// chip. Measured on the assembled unit: noiseStdDev 22-50 counts, raw wandering across a
// ~100-count band. 8 counts is comfortably inside that band (so live dither always
// clears it) and far below any real weight change (~0.02 g at the current calibration
// factor), while a truly wedged HX711 repeats one exact value forever and never clears
// it. This is what the comment above always described; the old check just didn't
// implement it.
volatile uint32_t g_scaleRecoveries = 0;    // how many times the watchdog fired since boot
volatile uint32_t g_scaleLastRecoveryMs = 0;
static const long SCALE_STUCK_TOLERANCE = 8;  // ADC counts, see above
static const uint32_t SCALE_STUCK_MS = 5000;  // frozen this long -> power-cycle the HX711
volatile uint8_t g_scaleNoiseIdx = 0;

String g_lastUid = "";       // UID of the last detected tag (hex), from the PN5180 poll
String g_lastTagData = "";   // text read back from the tag (ID pages)
long g_lastSpoolId = -1;     // databaseId parsed from the tag (-1 = none)

// PN5180 (ISO15693/NFC-V) test state — set by the loop poll, readable via /nfc5180.
String g_pn5180Uid = "";
bool g_pn5180Present = false;

// Tag poll cadence. Every tick energises the RF field, so this is the single largest
// periodic current draw on the 5V rail -- hence 750ms rather than the original 500ms:
// still fast enough that placing a spool feels immediate, but a third fewer RF cycles.
// Anything that needs a duration must be expressed in MILLISECONDS, never in a count
// of poll ticks: tick counts silently change meaning when this constant moves (the
// flow-reset debounce used to do exactly that -- see flowOnTagGone).
static const uint32_t PN5180_POLL_INTERVAL_MS = 750;

// NFC debug mode: a web UI toggle. ON = the reader only reads and reports the tag
// TYPE (NFC-V/NFC-A) + UID/ATQA/SAK, no normal flow. OFF = normal operation
// (ISO15693 poll every PN5180_POLL_INTERVAL_MS, sets g_pn5180Uid/g_pn5180Present
// for /nfc5180 + the flow).
bool g_nfcDebug = false;
PN5180ProbeResult g_nfcProbe;   // latest debug result, readable via /nfcprobe
// Debug mode toggled via HTTP (core 1), but pn5180Recover() touches the PN5180 SPI
// object shared with pn5180Task (core 0) -> delegate via flag, same as g_tareReq.
volatile bool g_nfcDebugChangeReq = false;

// TFT screen preview (web UI System tab) toggled via HTTP (core 1), but the actual TFT
// draw calls (g_tft.*) all happen on core 0 inside pn5180Task/menuTick -> same
// delegate-via-flag pattern as g_nfcDebugChangeReq, never touch the TFT from here.
volatile bool g_menuPreviewReq = false;
volatile bool g_menuPreviewReqOn = false;
volatile bool g_menuPreviewStepReq = false;  // ?next=1 -- advance one screen, no encoder

// Test menu (hidden diagnostics, see menu.h MENU_TEST*) LED override: true while
// either the physical LED test screen or the web UI's "Diagnostics" card owns the
// pixels directly. ledTick() (below, defined BEFORE menu.h is included, so it cannot
// reference the MenuScreen enum directly -- hence this decoupled bool) checks this
// FIRST and backs off entirely, else it would overwrite a test color with the normal
// idle/flash color on its very next tick.
volatile bool g_ledTestActive = false;
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
void loop() {
  // Only HTTP/OTA in loop() -> never blocked by sensors. HX711 (scaleTask) and
  // PN5180 (pn5180Task) run in their own tasks on core 0, loop/WiFi on core 1.
  //
  // Rough CPU load approximation (loop task): measures how much time per second goes
  // into actual work (handleClient/DB/OTA) vs. the trailing vTaskDelay(2ms).
  // busy / (busy + idle) ~ load. No menuconfig needed, but it's only an approximation
  // (not the only activity on core 1 - the WiFi stack runs alongside).
  unsigned long t0 = micros();
  ArduinoOTA.handle();
  server.handleClient();
  buzzerTick();   // advance the buzzer sequence from the loop context too
  // The DB check runs here (loop task), not in pn5180Task: the SpoolManagerExtended HTTP
  // bridge call blocks briefly and shouldn't hold up the reader task. Only on a new
  // tag with a valid ID.
  if (g_flowDbRequest) runDbCheck();
  // TFT menu delegation: run blocking flow transitions in the loop() task (core 1).
  if (g_flowMenuReq != FMA_NONE) {
    FlowMenuAction a = g_flowMenuReq;
    int arg = g_flowMenuArg;
    g_flowMenuReq = FMA_NONE;
    if (a == FMA_PRINTER) flowDoPrinter(arg);
    else if (a == FMA_TOOL) flowDoTool(arg);
    else if (a == FMA_WEIGH_SAVE) flowDoWeighSave();
  }

  // DB reachability ping moved to its own task (dbPingTask, core 0) -- see there for
  // why: octoToolCount()'s HTTPClient call can block for the full 3-4s connect+read
  // timeout when the printer is unreachable, and that used to run right here in
  // loop(), freezing server.handleClient() (and everything else in loop(), including
  // ledTick()) for the whole timeout every 60s.
  ledTick();  // update the WS2812 status LED (flashes -> back to idle)

  // PN5180 poll, debug probe, encoder + writing run in pn5180Task (core 0), NOT here:
  // the PN5180 library blocks (unbounded while-loops) and would otherwise freeze the
  // web server.

  unsigned long busy = micros() - t0;  // time spent working this iteration

  g_cpuBusyAccum += busy;  // average the load over a 1s window
  unsigned long now = millis();
  if (now - g_cpuWinStart >= 1000) {
    unsigned long win = (now - g_cpuWinStart) * 1000UL;  // window length in us
    g_cpuLoad = win ? (uint8_t)min<unsigned long>(100, (g_cpuBusyAccum * 100UL) / win) : 0;
    g_cpuBusyAccum = 0;

    // Dual-core load from the idle-counter deltas (rate/s against a calibrated baseline).
    static uint32_t lastIdle[2] = {0, 0};
    for (int c = 0; c < 2; c++) {
      uint32_t cur = g_idleCtr[c];
      uint32_t rate = (uint32_t)(((uint64_t)(cur - lastIdle[c]) * 1000UL) / (now - g_cpuWinStart));
      lastIdle[c] = cur;
      if (rate > g_idleBaseline[c]) g_idleBaseline[c] = rate;  // learn the idle maximum
      uint32_t load = g_idleBaseline[c] ? 100 - min<uint32_t>(100, (rate * 100UL) / g_idleBaseline[c]) : 0;
      g_coreLoad[c] = (uint8_t)load;
    }
    g_cpuWinStart = now;
  }

  vTaskDelay(pdMS_TO_TICKS(2));  // give the WiFi stack CPU time (counts as idle)
}

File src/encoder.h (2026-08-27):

#pragma once
#include <Arduino.h>

// encoder.h — EC11 rotary encoder (A/B) + encoder push + separate start button (KO).
// Module S11-05. A=15, B=16, PUSH=17, KO=18 (all INPUT_PULLUP, other side to GND).
// Rotation is interrupt-based (no poll losses), buttons are debounced.
//
// Usage: encoderInit() in setup(), encoderTick() in loop(). State via
// encoderPosition()/encoderTakeDelta() + encoderPush*/encoderStart*.

extern const int ENC_A;
extern const int ENC_B;
extern const int ENC_SW;
extern const int KEY_START;

// --- Rotary encoder (quadrature, ISR with a state table) -------------------
// Robust against both bounce and missed edges: BOTH pins (A+B) trigger the interrupt
// (CHANGE). A lookup table maps old+new 2-bit state to a VALID quadrature transition
// (+1/-1); bounce/double states resolve to 0 and are dropped. An EC11 produces 4 valid
// transitions per detent, so we accumulate in g_encSub and only emit a detent
// (g_encPos +/-1) at +/-4 — no skipping, no missed step, exactly one menu step per detent.
static volatile long g_encPos = 0;      // absolute position (detents)
static long g_encLastReported = 0;      // for delta queries
static volatile int8_t g_encSub = 0;    // sub-steps within a detent (-4..+4)
static volatile uint8_t g_encPrev = 0;  // previous 2-bit state (A<<1|B)

// Quadrature transition table: index = (prev<<2)|cur, value = +1/-1 (valid) or 0.
static const int8_t ENC_QTAB[16] = {
   0, -1, +1,  0,
  +1,  0,  0, -1,
  -1,  0,  0, +1,
   0, +1, -1,  0
};

static void IRAM_ATTR encIsr() {
  uint8_t cur = (uint8_t)((digitalRead(ENC_A) << 1) | digitalRead(ENC_B));
  int8_t d = ENC_QTAB[(g_encPrev << 2) | cur];
  g_encPrev = cur;
  if (d == 0) return;                    // invalid (bounce) -> ignore
  g_encSub += d;
  if (g_encSub >= 4)      { g_encPos++; g_encSub = 0; }   // full detent forward
  else if (g_encSub <= -4){ g_encPos--; g_encSub = 0; }   // full detent backward
}

// --- Buttons (interrupt-latched, active LOW) --------------------------------
// Earlier polling-based debounce (btnUpdate in encoderTick) lost presses whenever the
// task was stuck in a blocking PN5180 read between two encoderTick() calls (up to
// ~500 ms): a short press+release fell entirely between two reads. Now a FALLING ISR
// latches every press IMMEDIATELY (with timestamp debounce), regardless of what the
// task is doing. Consumed via encoderPushPressed().
struct IsrButton {
  int pin;
  volatile bool pressed = false;     // latched one-shot event (ISR sets, read clears)
  volatile uint32_t lastEdgeMs = 0;  // debounce timestamp
  volatile uint32_t count = 0;       // cumulative (HTTP status / backlight activity)
};

static IsrButton g_btnPush;   // encoder click (PUSH)
static IsrButton g_btnStart;  // start button (KO)

// Debug-log analysis on real hardware showed double-triggers ~130-140ms apart (not the
// few-ms contact chatter 120ms was sized for -- this button mechanically "re-bounces"
// on release over a longer window). 250 ms covers that with margin; still short enough
// that back-to-back intentional presses (menu confirm, then another) don't feel laggy.
static void IRAM_ATTR btnIsr(IsrButton &b) {
  uint32_t now = millis();
  if (now - b.lastEdgeMs < 250) return;  // debounce
  b.lastEdgeMs = now;
  if (digitalRead(b.pin) == LOW) { b.pressed = true; b.count++; }  // real falling edge
}
static void IRAM_ATTR pushIsr()  { btnIsr(g_btnPush); }
static void IRAM_ATTR startIsr() { btnIsr(g_btnStart); }

inline void encoderInit() {
  pinMode(ENC_A, INPUT_PULLUP);
  pinMode(ENC_B, INPUT_PULLUP);
  pinMode(ENC_SW, INPUT_PULLUP);
  pinMode(KEY_START, INPUT_PULLUP);
  g_btnPush.pin = ENC_SW;
  g_btnStart.pin = KEY_START;
  g_encPrev = (uint8_t)((digitalRead(ENC_A) << 1) | digitalRead(ENC_B));
  attachInterrupt(digitalPinToInterrupt(ENC_A), encIsr, CHANGE);
  attachInterrupt(digitalPinToInterrupt(ENC_B), encIsr, CHANGE);
  attachInterrupt(digitalPinToInterrupt(ENC_SW), pushIsr, FALLING);
  attachInterrupt(digitalPinToInterrupt(KEY_START), startIsr, FALLING);
}

// Buttons run entirely via ISR now; kept as a no-op for API compatibility.
inline void encoderTick() {}

inline long encoderPosition() { return g_encPos; }

// Change since the last call (for "N steps turned"). Resets the counter.
inline long encoderTakeDelta() {
  long now = g_encPos;
  long d = now - g_encLastReported;
  g_encLastReported = now;
  return d;
}

// One-shot flag: was PUSH/KO pressed since the last check? (consumes the ISR latch)
inline bool encoderPushPressed()  { bool e = g_btnPush.pressed;  g_btnPush.pressed = false;  return e; }
inline bool encoderStartPressed() { bool e = g_btnStart.pressed; g_btnStart.pressed = false; return e; }

inline bool encoderPushDown()  { return digitalRead(g_btnPush.pin) == LOW; }
inline bool encoderStartDown() { return digitalRead(g_btnStart.pin) == LOW; }

inline uint32_t encoderPushCount()  { return g_btnPush.count; }
inline uint32_t encoderStartCount() { return g_btnStart.count; }

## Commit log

2026-08-27 feat: initial commit — OctoScale NFC filament scale firmware
    ESP32-S3 device combining an HX711 load cell, a PN5180 NFC reader,
    an ST7789 TFT menu and a web UI for filament spool management.
    Reads and writes NFC-A/NTAG, NFC-V/ISO15693 and Mifare Classic 1K in
    seven payload formats, including the open OpenSpool, OpenPrintTag and
    TigerTag standards. Tag lookups, spool loading and weight write-back
    run against OctoPrint-SpoolManagerExtended over HTTP; without that
    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
    [OcroScale_Top_V4.stl]
2026-09-07 Add new STL files for OctoScale components and a script to regenerate VLW smooth-font headers
    - Added STL files: OcroScale_Top.stl, OctoScaleBottom.stl, OctoScaleButtonCover.stl, OctoScaleKnobCover.stl, OctoScaleLit.stl, OctoScaleScreenBazel.stl, and OctoScaleSpacer.stl.
    - Introduced a new Python script (make_vlw.py) to regenerate VLW smooth-font headers used by menu.h, ensuring existing glyphs remain byte-identical while appending missing codepoints.
    [OcroScale_Top.stl, OctoScaleBottom.stl, OctoScaleButtonCover.stl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]
2026-09-10 feat: add OctoScaleLEDCover STL file and implement IRQ timeout patches in PN5180 library
    [OctoScaleLEDCover.stl]
2026-09-10 feat: add drying temperature and time fields to Extended NFC layouts
2026-09-10 Enhance glyph rendering by expanding printable ASCII range in OctoFontMid
    - Added full printable ASCII range (0x20 to 0x7F) to the glyph set for OctoFontMid.
    - This change ensures that punctuation in names, vendors, and material strings renders correctly instead of displaying as missing glyphs.
    - Retained the existing range (0xA0 to 0x100) while excluding 0xAD to maintain compatibility.
2026-09-13 Add comprehensive documentation for OctoScale project
    - Introduced Development-Guide.md detailing hardware, build, and configuration specifics for the ESP32-S3-N16R8 target.
    - Created Features.md summarizing device capabilities, NFC tag formats, and interface features.
    - Added Project-Guide.md consolidating hardware, assembly, firmware, setup, architecture, and contribution guidelines.
    - Established User-Guide.md as a placeholder for future user documentation.
    - Included STL file for OctoScale top plate in the stl_files directory.
    [OctoScale_Top.stl]
2026-09-13 feat: implement firmware update check with privacy considerations and UI enhancements (#4)
    This pull request adds an automatic online firmware update check to the
    OctoScale device, improves the user interface for firmware updates, and
    provides users with more control and visibility over firmware versions.
    The main changes are grouped into firmware update checking, web UI
    improvements, and backend API additions.
    **Summary of most important changes:**
    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
2026-09-13 feat: implement WebUI polling and tab ownership management (#5)
    This pull request improves how the WebUI manages periodic status polling
    and tab ownership, ensuring that only the active tab makes network
    requests and background polling is stopped when a tab is hidden or
    inactive. This reduces unnecessary network traffic and keeps the UI
    responsive and efficient. The main changes are:
    **WebUI Polling and Tab Ownership Improvements:**
    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
2026-09-13 feat: implement independent status polling for system and WiFi status (#7)
    This pull request improves the responsiveness and reliability of the
    status indicators in the web UI by introducing a separate, lightweight
    polling mechanism for header status LEDs and refining how WiFi status
    updates are handled. The changes ensure that status LEDs remain
    up-to-date regardless of the active tab and after tab switches.
    **Web UI status polling improvements:**
    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
2026-09-15 fix: adjust PN5180 polling interval and improve WebUI polling behavior (#9)
    This pull request focuses on improving the robustness and clarity of the
    NFC polling and user interface polling cadence, making timing and
    polling logic more maintainable and less error-prone. The main changes
    include making poll intervals explicit and time-based, updating debounce
    and timeout logic to use milliseconds instead of tick counts, and
    refining the web UI's polling behavior to prevent unnecessary background
    requests.
    **NFC Polling and Timing Improvements:**
    * Introduced a new constant `PN5180_POLL_INTERVAL_MS` (750ms) to
    explicitly control the NFC tag polling interval, replacing hardcoded
    500ms values th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
    [main.cpp]
2026-09-15 Fix black color handling and derive OpenSpool color_hex correctly (#10)
    This pull request significantly refactors how color information is
    parsed, stored, and round-tripped across all NFC tag formats. The
    changes centralize the color parsing logic, ensure correct handling of
    multi-color and special color states (like transparent and rainbow), and
    guarantee that color data is consistently available in both the primary
    color field and the extended color grammar. The update also introduces a
    new function to compose color grammar strings from parsed data, ensuring
    reliable round-tripping and more robust handling of black and unset
    colors.
    **Centralization and Consistency of Color Handling:**
    *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
    [main.cpp, openprinttag.h, pn5180nfc.h]
2026-09-15 Document the two board supply capacitors (#12)
    This pull request updates the documentation to provide clearer and more
    detailed instructions regarding power supply decoupling and required
    capacitors for the hardware build. The changes emphasize correct
    capacitor selection, placement, and their importance in preventing
    power-related issues such as brownouts and unreliable operation.
    **Hardware requirements and assembly documentation:**
    * Added two new mandatory capacitors (1500 uF for the ESP32-S3 5V pin
    and 100 uF for the ESP32-S3 3.3V pin) to the hardware parts list in
    `docs/Hardware-and-Printing-Guide.md`, including recommended voltage
    ratings.
    * Expanded assembly instructions in `docs/A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
2026-09-15 docs: restore wiki-only content and move the 3.3 V capacitor to the converter
    The wiki is currently missing content and carries one wrong instruction.
    Both come from the same mistake: docs/ was older than the wiki, and the
    first wiki-sync run pushed that stale copy over it.
    Restored, by taking the pre-sync wiki state as the base and re-applying
    the documentation additions on top:
    - Thumbnail previews in the BOM, wiring, and printed-parts tables. Nine
    of 29 images were lost; the Hardware and Printing Guide is live with 11
    where it should have 18.
    - Wiki-relative links such as [Setup Guide](Setup-Guide), which the sync
    had rewritten as absolute GitHub URLs.
    Verified by diffing against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
2026-09-15 Fill the User Guide with operating instructions and UI mockups (#14)
    This pull request adds a comprehensive and user-friendly guide to the
    `docs/User-Guide.md` file, replacing the placeholder content with
    detailed instructions and explanations for day-to-day operation of the
    OctoScale device. The new documentation covers initial setup, hardware
    confirmation, usage of the TFT menu and web UI, troubleshooting, and
    more, complete with illustrative images and step-by-step guidance.
    Documentation improvements:
    * Replaced the placeholder user guide with extensive documentation
    covering device setup, operation, menu navigation, web UI usage, and
    troubleshooting steps, including images and detaile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
2026-09-15 Note that fwVersion cannot distinguish the pre- and post-fix behaviour (#16)
    This pull request adds important clarifications to the documentation
    regarding the handling of color fields and firmware versioning for
    devices. The new guidance helps prevent silent breakage in consumers by
    explaining the implications of the recent black-color fix and the
    limitations of using `fwVersion` for runtime detection.
    Documentation updates on color handling and firmware versioning:
    * Expanded the release note section in `docs/Development-Guide.md` to
    clarify that `fwVersion` does not distinguish between devices built
    before or after the black-color fix, and that consumers should not
    branch on `fwVersion`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
2026-09-16 Add OctoScale wiring documentation and symbol library (#17)
    This pull request makes several improvements and clarifications to the
    documentation for OctoScale, focusing on hardware wiring, assembly, and
    user guidance. The changes add a new wiring diagram, clarify assembly
    and power warnings, update part descriptions, and improve the clarity
    and accuracy of setup instructions.
    **Documentation improvements and new resources:**
    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
    [OctoScale-Wiring.kicad_sch]
2026-09-16 Enhance weight synchronization and update repository link (#18)
    This pull request introduces several improvements to how measured and
    remaining weights are handled and synchronized between the database and
    NFC tags, as well as enhances the reliability and accuracy of weight
    data. The changes ensure that the database's recomputed values are used
    for NFC tag updates, rounding errors are minimized, and the system
    gracefully handles tags that do not support certain fields.
    **Database and NFC tag synchronization improvements:**
    * `src/octoprint.h`, `src/main.cpp`: When saving a new measured weight,
    the system now retrieves the recomputed `usedWeight` and `usedLength`
    from the database response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
    [main.cpp, octoprint.h, pn5180nfc.h]
2026-09-16 Add reboot functionality to web UI and update user guide (#19)
    This pull request adds a new "Restart device" feature to the web UI and
    backend, allowing users to safely reboot the hardware from the
    interface. The implementation ensures that restarts are only allowed
    when safe, provides clear user feedback, and integrates seamlessly with
    the existing UI update flow.
    **New device restart feature:**
    * Added a `/reboot` HTTP POST endpoint to the backend (`src/main.cpp`)
    that safely restarts the device, refusing the request if a firmware
    update is in progress and ensuring the client receives a response before
    rebooting.
    * Updated the web UI (`src/web_ui.h`) to include a "Restart device"
    button,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
    [main.cpp]
2026-09-16 Implement backup and restore functionality for device settings (#20)
    This pull request significantly enhances the configuration backup and
    restore system to include all device settings (display, buzzer, LED,
    etc.) in addition to the existing calibration and OctoPrint instance
    data. The changes ensure that backups now capture the complete device
    state, and restores apply all settings immediately without requiring a
    reboot. The backup format remains compatible with older firmware,
    gracefully ignoring unknown fields.
    **Device Settings Backup and Restore:**
    - Added a settings table (`BK_SETTINGS`) in `backup.h` that enumerates
    all device settings (display, buzzer, LED, theme, debug, firmware c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
    [main.cpp]
2026-09-22 Nfc flow improvements (#22)
    This pull request makes significant improvements to the firmware's
    handling of scale zero-point verification, persistent storage, and
    diagnostics, with extensive documentation updates to match. It
    introduces a robust system for distinguishing between credible and
    unverified database IDs on NFC tags, enhances the development build
    process with unique build numbering, and improves user feedback and
    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
2026-10-02 Enhance display and backlight management with diagnostics and web UI updates (#26)
    This pull request introduces several improvements and diagnostic
    features to the display, backlight, and debugging subsystems, along with
    updated documentation to reflect these changes. The most significant
    updates include enhanced control over the display backlight (including a
    true "off" state), new diagnostics endpoints and logging for
    troubleshooting display flicker and activity, and more detailed user and
    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
2026-10-02 Fix snprintf usage to prevent buffer overflow in chip die ID formatting (#27)
    This pull request simplifies and optimizes how the `dieId` is converted
    to a hexadecimal string in the `startWebServer()` function. The updated
    code eliminates unnecessary variable usage and makes the conversion
    logic clearer and more efficient.
    **Code simplification and efficiency:**
    * In `src/main.cpp`, the loop that formats the `dieId` as a hex string
    now directly writes two characters per byte at the correct offset,
    removing the need for a separate counter variable and making the code
    easier to read and maintain.
    [main.cpp]
2026-10-03 Improve backlight management and diagnostics in display module (#28)
    This pull request introduces several improvements to the backlight
    control and diagnostics for the TFT display, with a focus on ensuring
    correct PWM behavior and enhancing visibility into the hardware state.
    The changes also pin the build toolchain version to prevent
    incompatibilities with newer Arduino core releases.
    **Backlight Control and Diagnostics Improvements:**
    * Ensured that `ledcAttachPin()` is called before setting the backlight
    level in `displaySetBacklight`, preventing stale or incorrect PWM duty
    cycles when waking the display (`src/display.h`).
    * Updated the `/diag` web endpoint to include additional fields: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
    [display.h, main.cpp]
2026-10-11 Fix/dbglog lock (#29)
    This pull request introduces several improvements and clarifications to
    the debug logging system, power supply documentation, and user-facing
    guides for the project. The most important changes include a complete
    rewrite of the in-memory debug log to support concurrent access and
    incremental polling, the addition of a persistent reset log feature, and
    updates to the hardware documentation to reflect a new recommended
    capacitor for the TFT display. These changes improve reliability,
    troubleshooting, and documentation accuracy.
    **Debug log improvements:**
    * The debug log ring buffer (`dbglog.h` and `main.cpp`) is now
    thread-safe, using a mutex to allow concurrent writers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
2026-11-05 docs: add icons to README badges (#31)
    Adds simple-icons logos to the shields.io badges in `README.md` (`logo=` + `logoColor=white`).
    | Badge | Icon |
    | --- | --- |
    | License | `gnu` |
    | Build | `githubactions` |
    | ESP32-S3 | `espressif` |
    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
2026-11-08 feat: enhance OpenSpool support with multi-color handling and budget calculations (#32)
    This pull request significantly improves OpenSpool tag handling by
    adding support for both short and long NDEF message frames, enabling
    larger JSON payloads (such as multi-color spools) and ensuring
    compatibility with existing and extended OpenSpool readers/writers. It
    also introduces proper reading and writing of additional spool colors,
    updates occupancy detection for long-form empty messages, and refactors
    several routines for clarity and maintainability.
    **OpenSpool NDEF framing and payload support:**
    - Added support for both short and long NDEF message frames in OpenSpool
    tag writing and reading, al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
2026-11-08 fix: refine NFC tag writing logic to ensure vendor and finish fields are only added when necessary (#33)
    This pull request improves how unsupported fields are reported and fixes
    a flow state issue when rewriting NFC tags in the `src/main.cpp` file.
    The main changes ensure that fields are only reported as unsupported
    when their corresponding IDs are missing, and that the system correctly
    resets flow state after a tag is rewritten, preventing stale data usage.
    **Improvements to unsupported field reporting:**
    *
    [`nfcWriteUnsupportedFields`](diffhunk://#diff-34d21af3c614ea3cee120df276c9c4ae95053830d7f1d3deaf009a4625409ad2L736-R739):
    Now only reports `vendor` as unsupported if `tigerTagBrandId`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
2026-11-08 fix: update NFC tag handling to support remaining weight updates for TigerTag and improve user guide (#34)
    This pull request introduces improved support for updating only the
    remaining weight field on TigerTag NFC tags during the filament weighing
    flow, instead of rewriting the entire tag. It adds a new write mode
    specifically for this purpose, ensures only compatible tags are updated,
    and clarifies which tag formats support partial updates. The changes
    also update user messaging and internal logic to accurately reflect what
    was written to the tag and why.
    **TigerTag partial update support:**
    - Added a new NFC write kind, `NFCWRITE_REMAINING`, to update only the
    `measure_available` (remaini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

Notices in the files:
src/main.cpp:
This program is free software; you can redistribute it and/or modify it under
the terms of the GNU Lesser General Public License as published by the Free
